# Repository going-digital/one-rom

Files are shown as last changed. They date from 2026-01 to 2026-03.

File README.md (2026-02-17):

# One ROM

**[One ROM](https://onerom.org) - One ROM To Rule Them All**

The most flexible ROM replacement for your retro computer.  It is highly configurable and low-cost.  Get them fabbed at JLC for under $5 each in a quantity of 10 or more.

Based on a Raspberry Pi RP2350 (One ROM Fire 🔥) or STM32F4 (One ROM Ice ❄️).

One ROM is available as 24 pin, 28 pin and 40 pin variants, emulating nearly all systems' 24 and 28 pin ROMs, plus 16-bit 40 pin ROMs used in systems like the Amiga A500.  One ROM supports any of the possible chip select configurations for 24 and 28 pin with a single hardware variant for that pin count, and can serve different images to multiple ROM sockets simultaneously.

Replaces failed ROMs in Commodore 64s, VIC-20s, PETs, Ataris, BBC, TIs, disk drives and many other types of systems, like pinball machines and music synthesizers.

ROM types replaced:
- 24 pin: 2704, 2708, 2716, 2732, 2316, 2332, 2364
- 28 pin: 2764, 27128, 27256, 27512, 23128, 23256, 23512, 231024
- 40 pin: 27C400

One ROM also supports RAM chips of the correct footprint, including the 6116 and 2016 2K SRAM chips.

One ROM shares firmware and configuration tools across all of its variants, making it a "one stop shop" for ROM replacement.

One ROM was formerly known as Software Defined Retro ROM (SDRR).

## Quick Start

See https://onerom.org/start/

## Hardware

These are the latest Fire 24 and 28 pin versions.  See [sdrr-pcb](sdrr-pcb/README.md) for all of the hardware designs and [current recommended revisions](sdrr-pcb/README.md#recommended-revisions).

<div style="display: flex; justify-content: center; gap: 20px;">
    One ROM RP2350 24 pin rev A side on
    One ROM RP2350 28 pin rev A side on
</div>

## Key Features

💰 Based on sub-$2 microcontrollers.  **[Choose from Raspberry Pi (Fire 🔥) or STM (Ice ❄️) flavours](docs/MCU-SELECTION.md)**.

⚡ **[Fast](docs/STM32-SELECTION.md)** enough for PETs, VIC-20s, C64s, BBCs, Ataris, TI-99, Apple II, 1541s, IEEE drives, etc. Support faster systems with higher end microcontroller.

📐 **[Same footprint](docs/images/sdrr-24-pin-side.png)** as original 24 and 28 pin ROMs - doesn't overhang the socket like other solutions.

🔌 **[USB Version](https://onerom.org/)** - no programmer required, program from your [browser](https://onerom.org/web) or [native desktop app](https://onerom.org/studio).

🚀 **[Quick programming](docs/PROGRAMMING.md)** - build and flash in <10 seconds.

🛠️ **[Reflash in situ](docs/PROGRAMMING.md)** - no need to remove the ROM from the host when reprogramming.

⚙️ **[Software configurable](docs/CONFIGURATION.md)** chip select lines - no hardware jumpers required.  Useful for replacing 23xxx series ROMs.

💾 Stores up to **[16 ROM images](docs/STM32-SELECTION.md)** of different sizes and chip select configurations.  Image selectable via jumpers.

📦 **[Replace multiple ROMs with one ROM](docs/MULTI-ROM-SETS.md)** a single One ROM 24 can replace up to 3 original ROMs e.g. all of C64 kernel, BASIC, character set.

🔀 **[Dynamic bank switching](docs/MULTI-ROM-SETS.md)** - switch between ROM images on the fly, e.g. different char ROMs with One ROM 24.

💻 **[Hackable at runtime](docs/RUNTIME-ACCESS.md)** - change the ROM images being served and access telemetry from the ROM at runtime using **[Airfrog](https://piers.rocks/u/airfrog)** or other SWD probes.

🧩 **[Images combined automatically](docs/CONFIGURATION.md)** - no need to manually build up your own larger PROM image containing multiple retro ROMs.

🏭 **[Two layer PCB](sdrr-pcb/README.md)**, component on single-side, limited BOM for low manufacturing cost/complexity.  Panelisable designs available for production quantities.

🔓 **[Open source](LICENSE.md)** software and hardware.

## Videos

Videos about One ROM, including demos, how-tos and technical deep-dives:

Video Title (https://www.youtube.com/playlist?list=PLXs34HaWLi12IR0gg25X8uovi9VFkOdlB)

## Documentation

The best place to started with One ROM is https://onerom.org/start/.

Links to other documentation provided below.

| Topic | Description |
|---|---|
| [Getting Started](docs/GETTING-STARTED.md) | Detailed instructions for flashing your One ROM |
| [Frequently Asked Questions](docs/FAQ.md) | Answers to common questions about One ROM. |
| [Building from source](ci/docker/README.md) | How to build the firmware from source using the provided Docker container. |
| [Installation](INSTALL.md) | Manual installation of build system dependencies. |
| [Programming](docs/PROGRAMMING.md) | How to program One ROM. |
| [Available Configurations](config/README.md#available-configurations) | Various pre-collated ROM collection configurations. |
| [MCU Selection](docs/MCU-SELECTION.md) | How to select the appropriate MCU for your application. |
| [Image Selection](docs/IMAGE-SELECTION.md) | How to tell One ROM which of the installed ROM images to serve. |
| [Image Sets](docs/MULTI-ROM-SETS.md) | How to use a single One ROM to support multiple ROMs simultaneously or to dynamically switch between images. |
| [Configuration](docs/CONFIGURATION.md) | One ROM configuration options. |
| [Runtime Access/Control](docs/RUNTIME-ACCESS.md) | Access and control the One ROM while it is serving ROMs. |
| [Compatibility](docs/COMPATIBILITY.md) | Compatibility with various retro systems. |
| [Logging](docs/LOGGING.md) | How to enable and use One ROM logging. |
| [Technical Summary](docs/TECHNICAL-SUMMARY.md) | Overview of the One ROM architecture, operation and design decisions. |
| [Technical Details](docs/TECHNICAL-DETAILS.md) | Technical details of the One ROM firmware and hardware. |
| [ROMs Glorious ROMs](docs/ROMS-GLORIOUS-ROMS.md) | Everything you ever wanted to know about 23/27 series ROMs but were afraid to ask. |
| [Custom Hardware](docs/CUSTOM-HARDWARE.md) | Guide on designing custom hardware for One ROM. |
| [Build System](docs/BUILD-SYSTEM.md) | How the One ROM build system works. |
| [Voltage Levels](docs/VOLTAGE-LEVELS.md) | How the One ROM supports the required logic voltage levels. |
| [Pi Pico Programmer](docs/PI-PICO-PROGRAMMER.md) | How to use a $5 Raspberry Pi Pico as a programmer for One ROM. |
| [Manufacturing Test](docs/MANUFACTURING-TEST.md) | Information on testing One ROM during manufacturing. |
| [STM32 Clones](docs/STM32-CLONES.md) | Information using STM32 clones with One ROM. |
| [Future Enhancements](docs/FUTURE-ENHANCEMENTS.md) | Possible future enhancements under consideration. |
| [License](LICENSE.md) | One ROM software and hardware licenses. |

## Debugging

The best place to start with debugging is [`Logging`](docs/LOGGING.md).  This will help you see what the One ROM is doing, and why it may not be working as expected.

If you have an [Airfrog](https://piers.rocks/u/airfrog), you can use it to inspect the One ROM firmware and its current state.

If you'd like a hand, raise an issue on the [GitHub issues page](https://github.com/piersfinlayson/software-defined-retro-rom/issues).  Please provide:

- the MCU you are using and the PCB type/revision
- the retro system you are trying to One ROM with
- any logging from One ROM
- ideally, the firmware image, if you are happy to share.

If you have built the firmware yourself, rather than using a pre-built release image, also provide:

- your build configuration
- the output from `make info-detail`.

## License

See [LICENSE](LICENSE.md) for software and hardware licensing information.

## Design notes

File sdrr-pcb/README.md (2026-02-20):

# sdrr-pcb

Contains SDRR PCB design files.  These are organised into two directories:

- [`verified/`](verified/README.md) - Verified designs that have been tested and work.
- [`unverified/`](unverified/README.md) - Unverified designs that have not been tested.

## Recommended Revisions

Last Updated 3rd February 2026.

I recommend Fire over Ice boards for most users.  See [MCU-SELECTION.md](../docs/MCU-SELECTION.md) for a comparison between Fire and Ice capabilities.

The following table lists the recommended verified designs.  Each design has been manufactured and assembled using JLCPCB's PCB assembly service, and verified to work correctly.

| Model | MCU | Pins | USB | SWD | Image Select Pins | X Pins | PCB |
|---|-----|---|-----|-----|---|---|---|
| Fire  | RP2350A | 24 | Micro-B | ✓ | 4 | 2 | [fire-24-d](./verified/fire-24-d/README.md) |
| Fire  | RP2354A | 24 | C | ✓ | 4 | 2 | [fire-24-e](./verified/fire-24-e/README.md) |
| Ice | STM32F4 | 24 | Micro-B | ✓ | 4 | 2 | [ice-24-j](./verified/ice-24-j/README.md) |
| Fire  | RP2350A or RP2354A | 28 | C | ✓ | 2 | n/a | [fire-28-a3](./verified/fire-28-a3/README.md) |
| Fire  | RP2350B or RP2354B | 40 | C | ✓ | 4 | n/a | [fire-40-a](./verified/fire-40-a/README.md) |

There may be later, unverified, revisions not in the list above.  These may have improvements over the recommended revisions, but they have not been verified to work.  If you want to use one of these later revisions, read the relevant README before ordering.

## Alternative Components

Sometimes your PCB manufacturer/assembler may be out of stock of a particular component.  This section lists some reasonable alternatives, using LCSC/JLC part numbers.

| Original Component | Original LCSC/JLC Part Number | Alternative Component | Alternative LCSC/JLC Part Number | Verified? | Notes |
|-|-|-|-|-|-|
| Diodes Inc AP2112K-3.3TRG1 | C51118 | Tech Public AP2112K-3.3TRG1 | C23380830 | No | Jelly bean part, same specs, should be fine |
| Raspberry Pi RP2350A | C42411118 | Raspberry Pi RP2354A | C41378174 | Yes | If using RP2354A, do not populate the external flash chip, as the RP2354A has internal flash. |
| Raspberry Pi RP2350B | C42415655 | Raspberry Pi RP2354B | C39843328 | Yes | If using RP2354B, do not populate the external flash chip, as the RP2354B has internal flash. |

The RP2354A can be replaced with the RP2350A _if the design supported external flash and it is populated_.
- Some designs, such as fire-24-e, do not support external flash, so the RP2354A cannot be replaced with the RP2350A.
- Some designs, such as fire-40-a, have hardware support for both external flash plus an RP2354B, so two lots of flash.  Fabricating this option requires the correct 0R resistors to be populated/not populated.  See the board schematic for more details.

In some cases, alternative BOM/POS files are already provided for some alternative components.  In other cases, you may need to edit the BOM/POS files yourself to substitute the alternative component.  _Always_ double check component values, part numbers and placement before ordering.

## Notes on Fabrication

All recommended designs have been manufactured and assembled using JLCPCB's PCB assembly service.  The gerbers and BOM/POS files in each revision's `fab/` directory are compatible with JLCPCB's requirements.

Some variants offer multiple sets of BOM/POS files or different combinations of components.  Read the relevant revision's README for details.

You need to exercise care when submitting the order to ensure the correct options are selected.  In particular:

- Select economic assembly, not standard assembly, for cost reasons.
- Use standard 1.6mm PCB thickness.  You probably want HASL with lead finish for cost reasons.
- You have to select the desired PCB colour as part of the PCB ordering process.  Red is recommended for Fire and blue for Ice.
- As of late 2025 you no longer need to remove JLC's order ID from the PCBs, but it is worth checking this is still the case when you place your order.
- After uploading the BOM and position files for assembly, you need to ensure all parts are available and checked.
- You must ensure JLC is showing the correct orientation for all components.  There are silkscreen markings for pin 1 on all ICs and polarized components - ensure this matches the pink dot of the component in the viewer.  Also ensure the USB connector is the correct orientation.

Occasionally, some chosen parts are out of stock on JLCPCB.  One ROM has been designed with extremely common parts where possible, which JLC tend to hold large stocks of.  However, if a part is unavailable you may need to select an alternative part.  Ensure the alternative part has the same footprint and electrical characteristics (e.g. capacitance, voltage rating, etc) as the original part.  If in doubt, query within github discussions for advice. 

JLC may raise an issue with you after submitting your order.  Common issues include:
- JLC may ask to add side rails with stamp holes, to help with the PCB assembly process.  While One ROM has been successfully fabbed without these, if JLC recommends them it is best to accept this change, as otherwise they may not warrant the assembled boards.  The side rails can be snapped off using the "mouse bites" (stamp holes) after assembly.  JLC may or may not accept replacing stamp holes with v-score - as v-score is not available on their economic service.

If in doubt, query within github discussions for advice.

Assembly errors:
- Ice boards have rarely, if ever, experienced assembly errors.
- The first few batches of Fire boards experienced some assembly issues, particularly with respect to the RP2350 MCU solder pad fillets.  More recent boards and orders have been without issue.  It is unclear whether differences in the later PCBs or improvements in JLC's assembly process are responsible for this improvement.  If you do experience assembly issues, raise with JLC support.  It would also be interesting to hear on github discussions what issues you experienced, so others can be aware.

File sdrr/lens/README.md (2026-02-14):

# One ROM Lens

This directory contains the source code for the One ROM Lens, a tool which runs the One ROM PIO algorithms in a browser and visualizes the results.

To build, first build the firmwre.  This must be done using the original `make` approach, as opposed to the newer `scripts/onerom.sh` approach.

```bash 
HW_REV=fire-24-e MCU=rp2350 ROM_CONFIGS=file=images/test/0_63_8192.rom,type=2364,cs1=0 make
```

Then, build and run One ROM Lens:

```bash
make -C sdrr -f lens.mk run
```

Point a browser at `http://localhost:8000` to access the One ROM Lens interface.

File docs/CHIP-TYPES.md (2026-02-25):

# Chip Type Specifications

This document provides detailed specifications for the different Chip types One ROM supports, and aims to support in future, including pinouts, control lines, and programming requirements.

The document is auto-generated from the [json/rom-types.json](/rust/config/json/rom-types.json) configuration file.  That file was created by researching datasheets for the various Chip types.

Some of the pin names have been modified from the datasheet values for consistency beween Chip types:

- /OE on 2704/2408 is called Program, but serves as /OE when in read mode.  Other 27xx ROMs use /OE for that pin, hence the /OE name is used here. 
- Similarly /CE on 2704/2708 ROMs is called /CS, but is called /CE for consistency with other ROM types.
- 23256/23512 chip select lines are often called CE/OE on datasheets, but are mask programmable to be active high or low, hence these are referred to within this doc as CS lines, like the other 23xx ROMs.

There are also some other inconsistencies between types:

- 2332's CS2 is pin 21 and pin 18 is A11.  On the 2316, CS2 is pin 18, and CS3 pin 21.
- The 2332's A11 is pin18, but the 2732's A11 is pin 21.

## Contents

- [24-pin Mask ROM Family (23xx)](#24-pin-mask-rom-family-23xx)
- [28-pin Mask ROM Family (23xxx)](#28-pin-mask-rom-family-23xx)
- [24-pin EPROM Family (27xx)](#24-pin-eprom-family-27xx)
- [28-pin EPROM Family (2764 and 27xxx)](#28-pin-eprom-family-27xx)
- [RAM Chips](#ram-chips)
- [Pin Function Comparison](#pin-function-comparison)
- [Detailed Pinouts](#detailed-pinouts)

## 24-pin Mask ROM Family (23xx)

| Chip Type | Size | Address Lines | Control Lines | Programming |
|---|---|---|---|---|
| 2316 | 2KB | 11 (A0-A10) | CS1 (pin 20), CS2 (pin 18), CS3 (pin 21) | None |
| 2332 | 4KB | 12 (A0-A11) | CS1 (pin 20), CS2 (pin 21) | None |
| 2364 | 8KB | 13 (A0-A12) | CS1 (pin 20) | None |

## 28-pin Mask ROM Family (23xx)

| Chip Type | Size | Address Lines | Control Lines | Programming |
|---|---|---|---|---|
| 23128 | 16KB | 14 (A0-A13) | CS1 (pin 20), CS2 (pin 22), CS3 (pin 27) | None |
| 23256 | 32KB | 15 (A0-A14) | CS1 (pin 20), CS2 (pin 22) | None |
| 23512 | 64KB | 16 (A0-A15) | CS1 (pin 20), CS2 (pin 22) | None |
| 231024 | 128KB | 17 (A0-A16) | CS1 (pin 20) | None |

## 24-pin EPROM Family (27xx)

| Chip Type | Size | Address Lines | Control Lines | Programming |
|---|---|---|---|---|
| 2704 | 512B | 9 (A0-A8) | /CE (pin 18), /OE (pin 20) | VPP: pin 18 (Low during read) |
| 2708 | 1KB | 10 (A0-A9) | /CE (pin 18), /OE (pin 20) | VPP: pin 18 (Low during read) |
| 2716 | 2KB | 11 (A0-A10) | /CE (pin 18), /OE (pin 20) | VPP: pin 21 (VCC during read) |
| 2732 | 4KB | 12 (A0-A11) | /CE (pin 18), /OE (pin 20) | VPP: pin 20 (Acts as /OE) |

## 28-pin EPROM Family (27xx)

| Chip Type | Size | Address Lines | Control Lines | Programming |
|---|---|---|---|---|
| 2764 | 8KB | 13 (A0-A12) | /CE (pin 20), /OE (pin 22) | VPP: pin 1 (VCC during read); /PGM: pin 27 (High during read) |
| 27128 | 16KB | 14 (A0-A13) | /CE (pin 20), /OE (pin 22) | VPP: pin 1 (VCC during read); /PGM: pin 27 (High during read) |
| 27256 | 32KB | 15 (A0-A14) | /CE (pin 20), /OE (pin 22) | VPP: pin 1 (VCC during read) |
| 27512 | 64KB | 16 (A0-A15) | /CE (pin 20), /OE (pin 22) | VPP: pin 22 (VCC during read) |
| 27C010 | 128KB | 17 (A0-A16) | /CE (pin 22), /OE (pin 24) | VPP: pin 1 (x); /PGM: pin 31 (x) |
| 27C301 | 128KB | 17 (A0-A16) | /CE (pin 22), /OE (pin 2) | VPP: pin 1 (x); /PGM: pin 31 (x) |
| 27C020 | 256KB | 18 (A0-A17) | /CE (pin 22), /OE (pin 24) | VPP: pin 1 (x); /PGM: pin 31 (x) |
| 27C040 | 512KB | 19 (A0-A18) | /CE (pin 22), /OE (pin 24) | VPP: pin 1 (x); /PGM: pin 22 (Acts as /OE) |
| 27C400 | 512KB | 19 (A0-A18) | /BYTE (pin 31), /CE (pin 10), /OE (pin 12) | VPP: pin 31 (word_size); /PGM: pin 10 (Acts as /OE) |
| 27C080 | 1024KB | 20 (A0-A19) | /CE (pin 22), /OE (pin 24) | VPP: pin 24 (Acts as /OE); /PGM: pin 22 (Acts as /OE) |

## RAM Chips

| Chip Type | Size | Address Lines | Control Lines | Programming |
|---|---|---|---|---|
| 6116 | 2KB | 11 (A0-A10) | /CE (pin 18), /OE (pin 20), /WRITE (pin 21) | None |

## Pin Function Comparison

### 24-pin Package

| Pin | 2316 | 2332 | 2364 | 2704 | 2708 | 2716 | 6116 | 2732 |
|-----|---|---|---|---|---|---|---|---|
| 1 | A7 | A7 | A7 | A7 | A7 | A7 | A7 | A7 |
| 2 | A6 | A6 | A6 | A6 | A6 | A6 | A6 | A6 |
| 3 | A5 | A5 | A5 | A5 | A5 | A5 | A5 | A5 |
| 4 | A4 | A4 | A4 | A4 | A4 | A4 | A4 | A4 |
| 5 | A3 | A3 | A3 | A3 | A3 | A3 | A3 | A3 |
| 6 | A2 | A2 | A2 | A2 | A2 | A2 | A2 | A2 |
| 7 | A1 | A1 | A1 | A1 | A1 | A1 | A1 | A1 |
| 8 | A0 | A0 | A0 | A0 | A0 | A0 | A0 | A0 |
| 9 | D0 | D0 | D0 | D0 | D0 | D0 | D0 | D0 |
| 10 | D1 | D1 | D1 | D1 | D1 | D1 | D1 | D1 |
| 11 | D2 | D2 | D2 | D2 | D2 | D2 | D2 | D2 |
| 12 | GND | GND | GND | GND | GND | GND | GND | GND |
| 13 | D3 | D3 | D3 | D3 | D3 | D3 | D3 | D3 |
| 14 | D4 | D4 | D4 | D4 | D4 | D4 | D4 | D4 |
| 15 | D5 | D5 | D5 | D5 | D5 | D5 | D5 | D5 |
| 16 | D6 | D6 | D6 | D6 | D6 | D6 | D6 | D6 |
| 17 | D7 | D7 | D7 | D7 | D7 | D7 | D7 | D7 |
| 18 | CS2 | A11 | A11 | /CE+VPP | /CE+VPP | /CE | /CE | /CE+PE |
| 19 | A10 | A10 | A10 | VDD | VDD | A10 | A10 | A10 |
| 20 | CS1 | CS1 | CS1 | /OE+PE | /OE+PE | /OE+PE | /OE | /OE+VPP |
| 21 | CS3 | CS2 | A12 | VBB | VBB | VPP | /WRITE | A11 |
| 22 | A9 | A9 | A9 | GND | A9 | A9 | A9 | A9 |
| 23 | A8 | A8 | A8 | A8 | A8 | A8 | A8 | A8 |
| 24 | VCC | VCC | VCC | VCC | VCC | VCC | VCC | VCC |

### 28-pin Package

| Pin | 23128 | 23256 | 23512 | 231024 | 2764 | 27128 | 27256 | 27512 |
|-----|---|---|---|---|---|---|---|---|
| 1 | NC | NC | A15 | A15 | VPP | VPP | VPP | A15 |
| 2 | A12 | A12 | A12 | A12 | A12 | A12 | A12 | A12 |
| 3 | A7 | A7 | A7 | A7 | A7 | A7 | A7 | A7 |
| 4 | A6 | A6 | A6 | A6 | A6 | A6 | A6 | A6 |
| 5 | A5 | A5 | A5 | A5 | A5 | A5 | A5 | A5 |
| 6 | A4 | A4 | A4 | A4 | A4 | A4 | A4 | A4 |
| 7 | A3 | A3 | A3 | A3 | A3 | A3 | A3 | A3 |
| 8 | A2 | A2 | A2 | A2 | A2 | A2 | A2 | A2 |
| 9 | A1 | A1 | A1 | A1 | A1 | A1 | A1 | A1 |
| 10 | A0 | A0 | A0 | A0 | A0 | A0 | A0 | A0 |
| 11 | D0 | D0 | D0 | D0 | D0 | D0 | D0 | D0 |
| 12 | D1 | D1 | D1 | D1 | D1 | D1 | D1 | D1 |
| 13 | D2 | D2 | D2 | D2 | D2 | D2 | D2 | D2 |
| 14 | GND | GND | GND | GND | GND | GND | GND | GND |
| 15 | D3 | D3 | D3 | D3 | D3 | D3 | D3 | D3 |
| 16 | D4 | D4 | D4 | D4 | D4 | D4 | D4 | D4 |
| 17 | D5 | D5 | D5 | D5 | D5 | D5 | D5 | D5 |
| 18 | D6 | D6 | D6 | D6 | D6 | D6 | D6 | D6 |
| 19 | D7 | D7 | D7 | D7 | D7 | D7 | D7 | D7 |
| 20 | CS1 | CS1 | CS1 | CS1 | /CE | /CE | /CE | /CE+PE |
| 21 | A10 | A10 | A10 | A10 | A10 | A10 | A10 | A10 |
| 22 | CS2 | CS2 | CS2 | A16 | /OE | /OE | /OE+PE | /OE+VPP |
| 23 | A11 | A11 | A11 | A11 | A11 | A11 | A11 | A11 |
| 24 | A9 | A9 | A9 | A9 | A9 | A9 | A9 | A9 |
| 25 | A8 | A8 | A8 | A8 | A8 | A8 | A8 | A8 |
| 26 | A13 | A13 | A13 | A13 | NC | A13 | A13 | A13 |
| 27 | CS3 | A14 | A14 | A14 | /PGM | /PGM | A14 | A14 |
| 28 | VCC | VCC | VCC | VCC | VCC | VCC | VCC | VCC |

## Detailed Pinouts

### 2316 - 2KB mask ROM with 3 configurable CS lines

**Package:** 24-pin DIP  
**Capacity:** 2048 bytes  
**Control:** 3 configurable CS lines  

| Function | Pins | Notes |
|---|---|---|
| Address (A0-A10) | 8,7,6,5,4,3,2,1,23,22,19 | 11 address lines |
| Data (D0-D7) | 9,10,11,13,14,15,16,17 | 8 data lines |
| CS1 | 20 | Configurable polarity |
| CS2 | 18 | Configurable polarity |
| CS3 | 21 | Configurable polarity |
| VCC | 24 | +5V |
| GND | 12 | 0V |

### 2332 - 4KB mask ROM with 2 configurable CS lines

**Package:** 24-pin DIP  
**Capacity:** 4096 bytes  
**Control:** 2 configurable CS lines  

| Function | Pins | Notes |
|---|---|---|
| Address (A0-A11) | 8,7,6,5,4,3,2,1,23,22,19,18 | 12 address lines |
| Data (D0-D7) | 9,10,11,13,14,15,16,17 | 8 data lines |
| CS1 | 20 | Configurable polarity |
| CS2 | 21 | Configurable polarity |
| VCC | 24 | +5V |
| GND | 12 | 0V |

### 2364 - 8KB mask ROM with 1 configurable CS line

**Package:** 24-pin DIP  
**Capacity:** 8192 bytes  
**Control:** 1 configurable CS line  

| Function | Pins | Notes |
|---|---|---|
| Address (A0-A12) | 8,7,6,5,4,3,2,1,23,22,19,18,21 | 13 address lines |
| Data (D0-D7) | 9,10,11,13,14,15,16,17 | 8 data lines |
| CS1 | 20 | Configurable polarity |
| VCC | 24 | +5V |
| GND | 12 | 0V |

### 23128 - 16KB mask ROM with 3 configurable CS lines

**Package:** 28-pin DIP  
**Capacity:** 16384 bytes  
**Control:** 3 configurable CS lines  

| Function | Pins | Notes |
|---|---|---|
| Address (A0-A13) | 10,9,8,7,6,5,4,3,25,24,21,23,2,26 | 14 address lines |
| Data (D0-D7) | 11,12,13,15,16,17,18,19 | 8 data lines |
| CS1 | 20 | Configurable polarity |
| CS2 | 22 | Configurable polarity |
| CS3 | 27 | Configurable polarity |
| VCC | 28 | +5V |
| GND | 14 | 0V |

### 23256 - 32KB mask ROM with 2 configurable CS lines

**Package:** 28-pin DIP  
**Capacity:** 32768 bytes  
**Control:** 2 configurable CS lines  

| Function | Pins | Notes |
|---|---|---|
| Address (A0-A14) | 10,9,8,7,6,5,4,3,25,24,21,23,2,26,27 | 15 address lines |
| Data (D0-D7) | 11,12,13,15,16,17,18,19 | 8 data lines |
| CS1 | 20 | Configurable polarity |
| CS2 | 22 | Configurable polarity |
| VCC | 28 | +5V |
| GND | 14 | 0V |

### 23512 - 64KB mask ROM with 2 configurable CS lines

**Package:** 28-pin DIP  
**Capacity:** 65536 bytes  
**Control:** 2 configurable CS lines  

| Function | Pins | Notes |
|---|---|---|
| Address (A0-A15) | 10,9,8,7,6,5,4,3,25,24,21,23,2,26,27,1 | 16 address lines |
| Data (D0-D7) | 11,12,13,15,16,17,18,19 | 8 data lines |
| CS1 | 20 | Configurable polarity |
| CS2 | 22 | Configurable polarity |
| VCC | 28 | +5V |
| GND | 14 | 0V |

### 231024 - 128KB mask ROM with 1 configurable CS line

**Package:** 28-pin DIP  
**Capacity:** 131072 bytes  
**Control:** 1 configurable CS line  

| Function | Pins | Notes |
|---|---|---|
| Address (A0-A16) | 10,9,8,7,6,5,4,3,25,24,21,23,2,26,27,1,22 | 17 address lines |
| Data (D0-D7) | 11,12,13,15,16,17,18,19 | 8 data lines |
| CS1 | 20 | Configurable polarity |
| VCC | 28 | +5V |
| GND | 14 | 0V |

### 2704 - 512B EPROM with multiple supply voltages

**Package:** 24-pin DIP  
**Capacity:** 512 bytes  
**Control:** /CE, /OE  

| Function | Pins | Notes |
|---|---|---|
| Address (A0-A8) | 8,7,6,5,4,3,2,1,23 | 9 address lines |
| Data (D0-D7) | 9,10,11,13,14,15,16,17 | 8 data lines |
| CE | 18 | Active low |
| OE | 20 | Active low |
| VPP | 18 | Low during read during read |
| PE | 20 | Low during read during read |
| VCC | 24 | +5V |
| VDD | 19 | +12V |
| VBB | 21 | -5V |
| GND | 12 | 0V |
| GND | 22 | 0V |

### 2708 - 1KB EPROM with multiple supply voltages

**Package:** 24-pin DIP  
**Capacity:** 1024 bytes  
**Control:** /CE, /OE  

| Function | Pins | Notes |
|---|---|---|
| Address (A0-A9) | 8,7,6,5,4,3,2,1,23,22 | 10 address lines |
| Data (D0-D7) | 9,10,11,13,14,15,16,17 | 8 data lines |
| CE | 18 | Active low |
| OE | 20 | Active low |
| VPP | 18 | Low during read during read |
| PE | 20 | Low during read during read |
| VCC | 24 | +5V |
| VDD | 19 | +12V |
| VBB | 21 | -5V |
| GND | 12 | 0V |

### 2716 - 2KB EPROM with fixed active-low CE/OE

**Package:** 24-pin DIP  
**Capacity:** 2048 bytes  
**Control:** /CE, /OE  

| Function | Pins | Notes |
|---|---|---|
| Address (A0-A10) | 8,7,6,5,4,3,2,1,23,22,19 | 11 address lines |
| Data (D0-D7) | 9,10,11,13,14,15,16,17 | 8 data lines |
| CE | 18 | Active low |
| OE | 20 | Active low |
| VPP | 21 | VCC during read during read |
| PE | 20 | Low during read during read |
| VCC | 24 | +5V |
| GND | 12 | 0V |

### 6116 - 2KB (2048 x 8-bit) Static RAM with fixed active-low CE/OE/WE

**Package:** 24-pin DIP  
**Capacity:** 2048 bytes  
**Control:** /CE, /OE, /WRITE  

| Function | Pins | Notes |
|---|---|---|
| Address (A0-A10) | 8,7,6,5,4,3,2,1,23,22,19 | 11 address lines |
| Data (D0-D7) | 9,10,11,13,14,15,16,17 | 8 data lines |
| CE | 18 | Active low |
| OE | 20 | Active low |
| WRITE | 21 | Active low |
| VCC | 24 | +5V |
| GND | 12 | 0V |

### 2732 - 4KB EPROM with fixed active-low CE and shared OE/VPP

**Package:** 24-pin DIP  
**Capacity:** 4096 bytes  
**Control:** /CE, /OE  

| Function | Pins | Notes |
|---|---|---|
| Address (A0-A11) | 8,7,6,5,4,3,2,1,23,22,19,21 | 12 address lines |
| Data (D0-D7) | 9,10,11,13,14,15,16,17 | 8 data lines |
| CE | 18 | Active low |
| OE | 20 | Active low |
| VPP | 20 | Acts as /OE during read |
| PE | 18 | Low during read during read |
| VCC | 24 | +5V |
| GND | 12 | 0V |

### 2764 - 8KB EPROM with fixed active-low CE/OE

**Package:** 28-pin DIP  
**Capacity:** 8192 bytes  
**Control:** /CE, /OE  

| Function | Pins | Notes |
|---|---|---|
| Address (A0-A12) | 10,9,8,7,6,5,4,3,25,24,21,23,2 | 13 address lines |
| Data (D0-D7) | 11,12,13,15,16,17,18,19 | 8 data lines |
| CE | 20 | Active low |
| OE | 22 | Active low |
| VPP | 1 | VCC during read during read |
| /PGM | 27 | High during read during read |
| VCC | 28 | +5V |
| GND | 14 | 0V |

### 27128 - 16KB EPROM with fixed active-low CE/OE

**Package:** 28-pin DIP  
**Capacity:** 16384 bytes  
**Control:** /CE, /OE  

| Function | Pins | Notes |
|---|---|---|
| Address (A0-A13) | 10,9,8,7,6,5,4,3,25,24,21,23,2,26 | 14 address lines |
| Data (D0-D7) | 11,12,13,15,16,17,18,19 | 8 data lines |
| CE | 20 | Active low |
| OE | 22 | Active low |
| VPP | 1 | VCC during read during read |
| /PGM | 27 | High during read during read |
| VCC | 28 | +5V |
| GND | 14 | 0V |

### 27256 - 32KB EPROM with fixed active-low CE/OE

**Package:** 28-pin DIP  
**Capacity:** 32768 bytes  
**Control:** /CE, /OE  

| Function | Pins | Notes |
|---|---|---|
| Address (A0-A14) | 10,9,8,7,6,5,4,3,25,24,21,23,2,26,27 | 15 address lines |
| Data (D0-D7) | 11,12,13,15,16,17,18,19 | 8 data lines |
| CE | 20 | Active low |
| OE | 22 | Active low |
| VPP | 1 | VCC during read during read |
| PE | 22 | Low during read during read |
| VCC | 28 | +5V |
| GND | 14 | 0V |

### 27512 - 64KB EPROM with fixed active-low CE/OE

**Package:** 28-pin DIP  
**Capacity:** 65536 bytes  
**Control:** /CE, /OE  

| Function | Pins | Notes |
|---|---|---|
| Address (A0-A15) | 10,9,8,7,6,5,4,3,25,24,21,23,2,26,27,1 | 16 address lines |
| Data (D0-D7) | 11,12,13,15,16,17,18,19 | 8 data lines |
| CE | 20 | Active low |
| OE | 22 | Active low |
| VPP | 22 | VCC during read during read |
| PE | 20 | Low during read during read |
| VCC | 28 | +5V |
| GND | 14 | 0V |

### 27C010 - 128KB EPROM with fixed active-low CE/OE

**Package:** 32-pin DIP  
**Capacity:** 131072 bytes  
**Control:** /CE, /OE  

| Function | Pins | Notes |
|---|---|---|
| Address (A0-A16) | 12,11,10,9,8,7,6,5,27,26,23,25,4,28,29,3,2 | 17 address lines |
| Data (D0-D7) | 13,14,15,17,18,19,20,21 | 8 data lines |
| CE | 22 | Active low |
| OE | 24 | Active low |
| VPP | 1 | x during read |
| /PGM | 31 | x during read |
| VCC | 32 | +5V |
| GND | 16 | 0V |

### 27C301 - 128KB EPROM with fixed active-low CE/OE

**Package:** 32-pin DIP  
**Capacity:** 131072 bytes  
**Control:** /CE, /OE  

| Function | Pins | Notes |
|---|---|---|
| Address (A0-A16) | 12,11,10,9,8,7,6,5,27,26,23,25,4,28,29,3,24 | 17 address lines |
| Data (D0-D7) | 13,14,15,17,18,19,20,21 | 8 data lines |
| CE | 22 | Active low |
| OE | 2 | Active low |
| VPP | 1 | x during read |
| /PGM | 31 | x during read |
| VCC | 32 | +5V |
| GND | 16 | 0V |

### 27C020 - 256KB EPROM with fixed active-low CE/OE

**Package:** 32-pin DIP  
**Capacity:** 262144 bytes  
**Control:** /CE, /OE  

| Function | Pins | Notes |
|---|---|---|
| Address (A0-A17) | 12,11,10,9,8,7,6,5,27,26,23,25,4,28,29,3,2,30 | 18 address lines |
| Data (D0-D7) | 13,14,15,17,18,19,20,21 | 8 data lines |
| CE | 22 | Active low |
| OE | 24 | Active low |
| VPP | 1 | x during read |
| /PGM | 31 | x during read |
| VCC | 32 | +5V |
| GND | 16 | 0V |

### 27C040 - 512KB EPROM with fixed active-low CE/OE

**Package:** 32-pin DIP  
**Capacity:** 524288 bytes  
**Control:** /CE, /OE  

| Function | Pins | Notes |
|---|---|---|
| Address (A0-A18) | 12,11,10,9,8,7,6,5,27,26,23,25,4,28,29,3,2,30,31 | 19 address lines |
| Data (D0-D7) | 13,14,15,17,18,19,20,21 | 8 data lines |
| CE | 22 | Active low |
| OE | 24 | Active low |
| VPP | 1 | x during read |
| /PGM | 22 | Acts as /OE during read |
| VCC | 32 | +5V |
| GND | 16 | 0V |

### 27C400 - 0.5MB EPROM with fixed active-low CE/OE

**Package:** 40-pin DIP  
**Capacity:** 524288 bytes  
**Control:** /BYTE, /CE, /OE  

| Function | Pins | Notes |
|---|---|---|
| Address (A0-A18) | 29,9,8,7,6,5,4,3,2,40,39,38,37,36,35,34,33,32,1 | 19 address lines |
| Data (D0-D7) | 13,15,17,19,22,24,26,28,14,16,18,20,23,25,27,29 | 8 data lines |
| BYTE | 31 | Active low |
| CE | 10 | Active low |
| OE | 12 | Active low |
| VPP | 31 | word_size during read |
| /PGM | 10 | Acts as /OE during read |
| VCC | 21 | +5V |
| GND | 11 | 0V |
| GND | 30 | 0V |

### 27C080 - 1MB EPROM with fixed active-low CE/OE

**Package:** 32-pin DIP  
**Capacity:** 1048576 bytes  
**Control:** /CE, /OE  

| Function | Pins | Notes |
|---|---|---|
| Address (A0-A19) | 12,11,10,9,8,7,6,5,27,26,23,25,4,28,29,3,2,30,31,1 | 20 address lines |
| Data (D0-D7) | 13,14,15,17,18,19,20,21 | 8 data lines |
| CE | 22 | Active low |
| OE | 24 | Active low |
| VPP | 24 | Acts as /OE during read |
| /PGM | 22 | Acts as /OE during read |
| VCC | 32 | +5V |
| GND | 16 | 0V |

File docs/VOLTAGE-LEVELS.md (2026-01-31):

# Voltage Levels

## Background

One of the biggest difficulties of this project, alongside hitting the timing requirements, was finding a microcontroller tha could support the 5V logic levels required by retro systems.

The STM32F1 series (64-bit variant) on the face of it has the required number of 5V tolerant (FT) GPIOs, but on further examination, there are not sufficient contiguous and starting at pin 0, FT pins on any port to hit the required performance - that is to allow the assembly code to perform optimal chip select comparisons, address lookups, and apply the results those to the data pins.

Therefore the STM32F4 series was initially chosen, followed by the RP2350, both to give sufficient raw horsepower (clock speed and flash instruction prefetch and cache), and also to provide the required FT hardware configuration.

There are two areas which are important to understand when considering voltage levels:
1. The logic level compatibility between One ROM and the retro system - that is, ensuring that One ROM's outputs are within the acceptable input levels of the retro system, and vice versa.  See [5V and 3.3V Logic Levels](#5v-and-33v-logic-levels).
2. The absolute maximum voltage levels that One ROM can tolerate on its pins, especially during power-on, when One ROM's MCU VDD is not yet at 3.3V.  See [Absolute Maximum VIN](#absolute-maximum-vin).

## 5V and 3.3V Logic Levels

As One ROM's purpose is to replace 5V logic level ROMs, it must be compatible with the voltage levels required by those systems.  We do this by examining and comparing the [STM32F411 datasheet](https://www.st.com/resource/en/datasheet/stm32f411re.pdf) (as a representative STM32F4 family chip) with the datasheets for the:

- [6502](http://www.6502.org/documents/datasheets/mos/mos_65ce02_mpu.pdf)
- [6567](http://www.6502.org/documents/datasheets/mos/mos_6567_vic_ii_preliminary.pdf) (C64 VIC-II chip)
- [6560/6561](http://www.6502.org/documents/datasheets/mos/mos_6560_6561_vic.pdf) (VIC-20 VIC chip)

(A similar analysis has been done for the RP2350, although at the highest GPIO drive strength, 12mA, the RP2350 strictly contravenes the requires specification.  Therefore One ROM Fire uses 8mA drive strength, which is within specification.)

### One ROM outputs, 6502 inputs

Note - One ROM's 5V outputs are the data lines, PA0-7.  These are set to "fast" speed, with IIO = +8mA.  We avoid "high" speed, as this can result in a maximum low output voltage VOL of 1.3V, which is too high for the 6502's maximum low input voltage VIL of 0.8V.

| One ROM VOL | 6502 VIL | 6567 VIL | 6560/6561 VIL |
|---|---|---|---|
| 0.4V | 0.8V | 0.8V | 0.4V |

One ROM's maxmimum low output voltage is less than the 6502/6567's maximum low input voltage, and the same as the 6560/6561, so we're good.

| One ROM VOH | 6502 VIH | 6567 VIH | 6560/6561 VIH |
|---|---|---|---|
| 2.4V* | 2.0V | 2.0V | 2.4V |

*Note it is highly likely the STM32F4 datasheet says that VOH is VDD-0.4V = 2.9V in this case - so we take 2.4V to be conservative.*

One ROM's maximum minimum output voltage is greater than the 6502/6567's minimum high input voltage, and the same as the 6560/6561, so we're good.

### One ROM inputs, 6502 outputs

| One ROM VIL | 6502 VOL | 6567 VOL | 6560/6561 VOL |
|---|---|---|---|
| 1.0V | 0.4V | 0.4V | 0.4V |

One ROM's minimum low input voltage is greater than the 6502/6567/6560/6561's maximum low output voltage so we're good.

| One ROM VIH | 6502 VOH | 6567 VOH | 6560/6561 VOH |
|---|---|---|---|
| 2.3V | 2.4V | 2.4V | 2.4V |

One ROM's minimum high input voltage is less than the 6502/6567/6560/6561's minimum high output voltage so we're good.

## Absolute Maximum VIN

According to the MCU datasheets, the absolute maximum rated voltage on any 5V tolerant pin is VDD + 4.0V for the STM32F4 and VDD + 3.63V on the RP2350.  There is also a 5.5V absolute maximum - so when VDD is at its usual 3.3V, the absolute maximum on any pin is 5.5V.

When VDD is 0V (before the voltage regulator is powering the chip), this means the absolute maximum voltage on any pin is 4.0V/3.63V (Ice/Fire).  When One ROM is installed in a retro system and powered on there is likely to be a 20us delay (see AP2112K-3.3TRG1 datasheet) between VCC being applied to One ROM and the voltage regulator outputting 3.3V to the MCU.

During this time then, technically, according to the MCUs' datasheets, the voltage on any GPIO must not exceed 4.0V/3.63V.  This is the case for most pins on most retro host systems as most systems have a reset circuit, and the bus master(s) are often held in reset for much longer than 20us - so most pins will be a 0V.  However, in some cases, some CS lines are permanently pulled to 5V, either through pull-ups or directly.  This means that 5.0V is applied to those pins for around 20us before VDD comes up to 3.3V.

System resets (where the internal host's reset line is used to reset the host system) typically do not trigger the 20us over-voltage scenario, as the MCU's VDD remains at already at 3.3V, as 5V remains applied to One ROM's VCC pin.  So, this applies to physical power-on (after power-off) events only.

To provide confidence in One ROM as a solution given its use strictly contravening the MCUs' datasheet figures, validation testing has been done with both Ice and Fire 24 boards, to ensure it is tolerant of 5.0V being applied to a single CS pin through a 0R resistor, across many power on events.

The test philosophy used was as follows:

- Use a 555 timer circuit to drive a transistor to power One ROM on and off - around 2.5s on, 1.5s off for a 4s/0.25Hz cycle.
- Hard pull (through a 0R resistor or wire) one CS pin (One ROM physical pin 20) to the 555/transistor switched VCC - i.e. it is powered at the same time as VCC is provided to One ROMs power pin, 24.
- Assume that a One ROM will receive, in heavy use, an average of 10 power cycles in any day = ~3600 cycles a year.  Hence one hour of testing (900 cycles) is equivalent to around 3 months of heavy use.
- Run the test for at least 24 hours = 6 years equivalent heavy use.
- After the test, validate that the all pins still operate correctly, by ensuring One ROM 24 can still serve a 2364 C64 kernal ROM in a C64.  If any address, data or CS line were damaged, the C64 would fail to boot.

Fire 24 serves as a reasonable proxy for Fire 28, as the designs are essentially identical, with a different GPIO mapping and couple more GPIOs used.

The 2.5s/1.5s timing was chosen, using convenient 555 circuit component values, to give One ROM plenty of time to fully boot and stabilise, and enough time for internal capacitors to meaningfully discharge during the off period, bringing VDD back down to close to zero before the next cycle.  Remember - during the period when VDD is 3.3V, all pins are fully 5v tolerant (up to 5.5V), so the testing is focused on the power-on period only.

Both Ice and Fire boards passed this test without issue.  The conclusion is that both One ROM Ice and Fire (using the STM32F4 and RP2350 respectively) can happily tolerate this over-voltage scenario under heavy use for extended periods of time.

The precise boards versions tested were:

- ice-24-f STM32F411RET6
- fire-24-d RP2350A, A4 stepping

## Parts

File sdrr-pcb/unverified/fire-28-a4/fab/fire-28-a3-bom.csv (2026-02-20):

Reference | Qty | Value | DNP | Exclude from BOM | Exclude from Board | Footprint | Datasheet | LCSC
C1,C2,C3,C7,C13,C15 | 6 | 4.7uF |  |  |  | Capacitor_SMD:C_0402_1005Metric | ~ | C23733
C4,C5,C6,C8,C9,C10,C11,C12,C14 | 9 | 0.1uF |  |  |  | Capacitor_SMD:C_0402_1005Metric | ~ | C1525
C16,C17 | 2 | 4.7uF |  |  |  | RP2350_60QFN_minimal:C_0402_1005Metric_small_pads | ~ | C23733
C18,C19 | 2 | 15pF |  |  |  | Capacitor_SMD:C_0402_1005Metric | ~ | C1548
D1 | 1 | LED_Small |  |  |  | LED_SMD:LED_0603_1608Metric | ~ | C2286
D2,D3 | 2 | 1N5819WS |  |  |  | Diode_SMD:D_SOD-323 |  | C191023
J1 | 1 | USB_C_Receptacle_USB2.0_16P |  |  |  | piers retro footprints:USB_C_connector_c2765186 | https://www.usb.org/sites/default/files/documents/usb_type-c.zip | C2765186
L1 | 1 | 3.3u |  |  |  | RP2350_60QFN_minimal:L_pol_2016 | ~ | C42411119
R1,R3,R7,R8 | 4 | 10K |  |  |  | Resistor_SMD:R_0402_1005Metric | ~ | C25744
R2,R5,R6 | 3 | 1K |  |  |  | Resistor_SMD:R_0402_1005Metric | ~ | C11702
R4 | 1 | 33R |  |  |  | Resistor_SMD:R_0402_1005Metric | ~ | C25105
R9,R10 | 2 | 5K1 |  |  |  | Resistor_SMD:R_0402_1005Metric | ~ | C25905
U1 | 1 | RP2350_60QFN |  |  |  | RP2350_60QFN_minimal:RP2350-QFN-60-1EP_7x7_P0.4mm_EP3.4x3.4mm_ThermalVias |  | C42411118
U3 | 1 | AP2112K-3.3 |  |  |  | Package_TO_SOT_SMD:SOT-23-5 |  | C51118
U4 | 1 | USBLC6-2P6 |  |  |  | Package_TO_SOT_SMD:SOT-666 | https://www.st.com/resource/en/datasheet/usblc6-2.pdf | C15999
U5 | 1 | W25Q16JVSS |  |  |  | Package_SON:Winbond_USON-8-1EP_3x2mm_P0.5mm_EP0.2x1.6mm | https://www.winbond.com/hq/support/documentation/levelOne.jsp?__locale=en&DocNo=DA00-W25Q16JV.1 | C2843335
Y1 | 1 | Crystal_GND24 |  |  |  | Crystal:Crystal_SMD_Abracon_ABM8G-4Pin_3.2x2.5mm | ~ | C20625731

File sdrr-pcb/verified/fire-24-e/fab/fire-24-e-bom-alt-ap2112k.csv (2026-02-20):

Reference | Qty | Value | DNP | Exclude from BOM | Exclude from Board | Footprint | Datasheet | LCSC
C1,C2,C7,C13,C15 | 5 | 4.7uF |  |  |  | Capacitor_SMD:C_0402_1005Metric | ~ | C23733
C3,C4,C5,C6,C8,C9,C10,C11,C12 | 9 | 0.1uF |  |  |  | Capacitor_SMD:C_0201_0603Metric | ~ | C668346
C16,C17 | 2 | 4.7uF |  |  |  | RP2350_60QFN_minimal:C_0402_1005Metric_small_pads | ~ | C23733
C18,C19 | 2 | 15pF |  |  |  | Capacitor_SMD:C_0201_0603Metric | ~ | C85891
D1 | 1 | LED_Small |  |  |  | LED_SMD:LED_0402_1005Metric | ~ | C25503345
D2,D3 | 2 | 1N5819WS |  |  |  | Diode_SMD:D_SOD-323 |  | C191023
J4 | 1 | USB_C_Receptacle_USB2.0_16P |  |  |  | piers retro:USB_C_connector_c2765186 | https://www.usb.org/sites/default/files/documents/usb_type-c.zip | C2765186
L1 | 1 | 3.3u |  |  |  | RP2350_60QFN_minimal:L_pol_2016 | ~ | C42411119
R1,R3,R7,R8 | 4 | 10K |  |  |  | Resistor_SMD:R_0201_0603Metric | ~ | C473048
R2,R5,R6 | 3 | 1K |  |  |  | Resistor_SMD:R_0201_0603Metric | ~ | C270365
R4 | 1 | 33R |  |  |  | Resistor_SMD:R_0402_1005Metric | ~ | C25105
R9,R10 | 2 | 5K1 |  |  |  | Resistor_SMD:R_0201_0603Metric | ~ | C270344
U1 | 1 | RP2350_60QFN |  |  |  | RP2350_60QFN_minimal:RP2350-QFN-60-1EP_7x7_P0.4mm_EP3.4x3.4mm_ThermalVias |  | C41378174
U3 | 1 | AP2112K-3.3 |  |  |  | Package_TO_SOT_SMD:SOT-23-5 |  | C23380830
U4 | 1 | USBLC6-2P6 |  |  |  | Package_TO_SOT_SMD:SOT-666 | https://www.st.com/resource/en/datasheet/usblc6-2.pdf | C15999
Y1 | 1 | Crystal_GND24 |  |  |  | Crystal:Crystal_SMD_Abracon_ABM8G-4Pin_3.2x2.5mm | ~ | C20625731

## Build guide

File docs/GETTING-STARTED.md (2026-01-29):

# Getting Started

## Contents

- [Important](#important)
- [USB One ROMs](#usb-one-roms)
- [Hardware Identification](#hardware-identification)
- [Programming One ROM via SWD (not USB)](#programming-one-rom-via-swd-not-usb)
- [Image Selection](#image-selection)
- [Bank Selection](#bank-selection)
- [Multi-ROM Sets](#multi-rom-sets)
- [Hardware Version Build Settings](#hardware-version-build-settings)
- [Recovering a Bricked Device](#recovering-a-bricked-device)

## Important

⚠️ **Do Not** externally power your One ROM device when it is installed in your retro system, other than via USB.

If the retro system is off or unplugged, this will cause your power supply and One ROM to attempt to power the entire 5V rail of your retro system, which may damage your One ROM, your retro system, your power supply or all of them.

You may program your One ROM when it is installed in your retro system, so long as it is powered on.  In this case **do not** provide external power.

⚠️ **Always** install One ROM in the correct orientation.  Pin 1 is clearly marked with a white L (corner) shape on the PCB.  The USB connector is always **at the other end** of the PCB from pin 1.

## USB One ROMs

Most people will be getting started with a USB One ROM device, which can be programmed over USB.  You are recommended to use either:

- [One ROM Studio](https://onerom.org/studio) - a desktop application for Windows, macOS and Linux
- [One ROM Web](https://onerom.org/web) - a web tool for programming One ROM from your browser.

See those links for more information on how to use those tools.

## Hardware Identification

Each variant of the One ROM hardware has a unique revision ID printed on the PCB, and the boards have different numbers of breakout pins at the top of the PCB.

Identify your One ROM hardware version using the following image - in particular look for the revision ID, or match with the number of pins at the top of the PCB.

Fire boards use the RP2350 microcontroller, Ice boards STM32.

Identify your One ROM Hardware Version

Not all later revisions are shown here - they are very similar to those shown, but with a different silkscreen marking.

## Programming One ROM via SWD (not USB)

You need an SWD programmer to program the One ROM hardware.  The Raspberry Pi Debug Probe and a Raspberry Pi Pico programmed as a Debug Probe are suitable programmers.  An ST-Link or any other SWD programmer should also work.

You need to connect 3 cables from the SWD programmer to the One ROM:
- SWDIO (data)
- SWCLK (clock)
- GND (ground)

For the programming pins locations see:
- [STM32 Revisions 24-D/E/F Programming Pins](#stm32-revisions-24-def-programming-pins)
- [STM32 Rev G and RP2350 Rev A Programming Pins](#stm32-rev-g-and-rp2350-rev-a-programming-pins)

You also need to power the One ROM in order to program it.  This is most easily done by installing it in a retro system, and powering it on.

Alternatively, you can power the One ROM from a 5V power supply by connecting to the 5V and GND [pins that usually connect the One ROM to the retro system](#external-power):
- GND to pin 12 (bottom left)
- 5V to pin 24 (top right)

At present, when using the standard One ROM programming utility `probe-rs`, the RP2350 version must also be manually put into DFU/bootloader mode to be programmed, by shorting BOOT to GND when One ROM is powered on.  See the [Recovering a Bricked Device](#recovering-a-bricked-device) section for details.

Once connected, you can run the appropriate `make` command from the repository root to build and flash the firmware.

### Example `make` Commands

One ROM rev G, STM32F405RG MCU, serving the standard set of C64 images:

```bash
HW_REV=24-g MCU=f405rg CONFIG=old-config/c64.mk run
```

One ROM rev A, RP2350 MCU, serving the standard set of VIC20 PAL images:

```bash
HW_REV=p24-a MCU=rp2350 CONFIG=old-config/vic20-pal.mk run
```

There are lots of other build configurations possible - see:
- [Hardware Version Build Settings](#hardware-version-build-settings) for standard `HW_REV` and `MCU` settings
- [config](/old-config/README.md) for a list of standard ROM image configurations
- [Advanced Configuration](/docs/CONFIGURATION.md) for other configuration options.

### Ice Revisions 24-D/E/F Programming Pins

Programming Pins for Revisions STM revs D/E/F

### Fire rev A and Ice Rev G Programming Pins

Programming Pins for Revisions STM rev G and RP rev A

### Fire rev C onwards and Ice Rev I Onwards Programming Pins

These are at the top of the board and are labelled on the underside of the board.

### External Power

External Power Pins

## Image Selection

One ROM supports a number of different ROM images being installed at once, with those images being selected by using the One ROM jumpers.  One ROM reads these jumpers at boot time to detect which image to serve.  Using this mechanism, One ROM will not dynamically switch between images while the retro system is running - see [Bank Selection](#bank-selection) below for dynamic switching.

The image select jumpers are always found at the top of the One ROM PCB, and differerent hardware revisions have different numbers of supported jumpers.

The images below show which jumper indicates which bit of the image selection value.  If closed, the bit is a 1, if open, the bit is a 0.  Therefore to select:
- image 0, leave all jumpers open
- image 1, close the jumper marked 0
- image 2, close the jumper marked 1
- image 3, close the jumpers marked 1 and 0
- etc.

If you select an image number higher than the total number of images installed, One ROM will start counting again from image 0.  For example:
- if you have 1 image installed, it will always be selected
- if you have 2 images installed, only bit 0 will take effect
- if you have 3 images installed and close jumper bits 1 and 0, image 0 will be selected (3 modulo 3 = 0)

### Fire Image Selection Jumpers

Fire 24 revision A has 3 image select jumpers, with the least significant bit on the **right**.  All subsequent Fire boards have the least significant bit on the right also, with the following number of image select jumpers:

Image Selection Jumpers for RP rev A

24 pin:

- A - 3
- B - 3
- C - 2
- D - 4

28 pin:

- A - 2

### Ice Revision 24-D Image Selection Jumpers

Revision D has 3 image select jumpers, with the least significant bit on the left.

Image Selection Jumpers for STM rev D

### Ice 24-E/F Image Selection Jumpers

Revisions E and F have 4 image select jumpers, with the least significant bit on the left.

Image Selection Jumpers for STM revs E/F

### Ice 24-G/H Image Selection Jumpers

Revision G has 5 image select jumpers, with the least significant bit on the **right**.

Image Selection Jumpers for STM revs G/H

## Ice 24-I/J Image Selection Jumpers

These revisions have 4 image select jumpers, with the least significant bit on the **right**.

## Bank Selection

When using [bank switched configurations](/docs/MULTI-ROM-SETS.md#dynamic-bank-switching-configuration) (those that start `bank-`), One ROM dynamically switches between images using the bank select jumpers ("X pins" or "expansion pins") X1 and X2.  These are always found at the top of the PCB.

Bank Selection Jumpers

Note that One ROM 28 does not have X pins. 

See the [Multi-ROM Sets](/docs/MULTI-ROM-SETS.md) documentation for more information on banks and multi-ROM sets.

## Multi-ROM Sets

When using [multi-ROM sets](/docs/MULTI-ROM-SETS.md#multi-rom-set-configuration) (those that start `set-`), One ROM serves ROM images up to 3 ROM sockets simultaneously, using pins X1 and X2 as extra chip select lines.  Connect flying leads from the X1 and X2 pins to the chip select pins of the other ROM sockets to be served.

Bank Selection Jumpers

Note that One ROM 28 does not have X pins. 

See the [Multi-ROM Sets](/docs/MULTI-ROM-SETS.md) documentation for more information on banks and multi-ROM sets.

## Hardware Version Build Settings

When building the One ROM firmware you must identify the hardware version and the MCU type to the build system.  The following table lists the identifiers to use for each hardware version:

| Type | Pins | PCB Revision ID  | `HW_REV=` | Supported `MCU=` | `STATUS_LED=` |
|---|---|-----|---|---|---|
| Fire | 24 | A | fire-24-a | rp2350 | 0/1 |
| Fire | 24 | B | fire-24-b | rp2350 | 0/1 |
| Fire | 24 | C | fire-24-c | rp2350 | 0/1 |
| Fire | 24 | D | fire-24-d | rp2350 | 0/1 |
| Fire | 28 | A/A2/A3 | fire-28-a | rp2350 | 0/1 |
| Ice | 24 | D | ice-24-d | f401rb/f401rc/f401re/f405rg/f411rc/f411re/f446rc/f446re | Not supported
| Ice | 24 | E | ice-24-e | f401rb/f401rc/f401re/f405rg/f411rc/f411re/f446rc/f446re | 0/1 |
| Ice | 24 | F/F2 | ice-24-f | f401rb/f401rc/f401re/f405rg/f411rc/f411re/f446rc/f446re | 0/1 |
| Ice | 24 | G | ice-24-g | f401rb/f401rc/f401re/f405rg/f411rc/f411re/f446rc/f446re | 0/1 |
| Ice | 24 | H | ice-24-h | f401rb/f401rc/f401re/f405rg/f411rc/f411re/f446rc/f446re | 0/1 |
| Ice | 24 | I | ice-24-i | f401rb/f401rc/f401re/f405rg/f411rc/f411re/f446rc/f446re | 0/1 |
| Ice | 24 | J | ice-24-j | f401rb/f401rc/f401re/f405rg/f411rc/f411re/f446rc/f446re | 0/1 |

Note that Fire boards can be fabbed with an RP2354 instead of the RP2350.  In this case the external flash should be un-populated.

## Recovering a Bricked Device

If your programmer will not connect to your One ROM device, or you have accidentally flashed incorrect firmware, you may have bricked your device and need to recover the device by forcing it into DFU/bootloader mode and then programming it using your SWD programmer as normal.

To enter DFU/bootloader mode, you must set the BOOT (Fire) or BOOT0 (Ice) pin to the correct level, and then reset the device, either by power cycling, replugging into USB or briefly pulling the RESET/RUN pin low.

## Fire

On the RP2350 BOOT must be pulled to GND, while resetting the device, to enter DFU/bootloader mode.  These should be shorted together to pull BOOT low.

Fire 24 rev A:

BOOT Pin Location - RP rev A

On Fire 24 B, BOOT and GND are exposed as pads on the board underside.

On Fire 24 C onwards and 28 A onwards, BOOT and GND are exposed at the top of the board and are labelled on the underside.

### Ice

On revisions D, E, and F, BOOT0 and 3.3V are exposed at the top right of the board as shown - short the two indicated pins together to pull BOOT0 high.

BOOT0 Pin Location - STM revs D/E/F

On revision G and H, BOOT0 and 3.3V are exposed at the bottom of the board as part of the programming pins, as shown.  Short the two indicated pins together to pull BOOT0 high.

BOOT0 Pin Location - STM rev G

On revisions I/J BOOT0 and 3.3V are exposed at the top of the board, and are labelled on the underside.

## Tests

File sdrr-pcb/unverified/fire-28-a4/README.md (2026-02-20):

# One ROM Fire 28 pin

**Unverified**

A4 revision of the 28 pin Fire ROM board.  Combined USB/Pro version with USB-C and SWD header pins.

This design only differs from A3 in a minor silkscreen clarification (see #121).

There are two versions of the BOM/POS files, which are unchanged from A3.

- The original version with an RP2350A and external flash
- A lower cost version with an RP2354A and no external flash

## Contents

- [Fab Files](fab/)
- [KiCad Design Files](kicad/)

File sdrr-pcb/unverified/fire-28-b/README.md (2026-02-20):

# One ROM Fire 28 pin

**Unverified**

Based on fire-28-a4, this design swaps out the horizontal USB-C connector for vertical one (i.e. that sticks up out of One ROM), to help when there is too little space at the bottom of a connector to plug in a cable.

This design is not preferred over fire-28-a - the two USB connector designs are complementary.

## Contents

- [Fab Files](fab/)
- [KiCad Design Files](kicad/)

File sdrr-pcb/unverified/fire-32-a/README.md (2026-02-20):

# One ROM Fire 32 pin

**Unverified**

Based on fire-40-a, this design is a prototype to add 32 pin One ROM support. 

## Contents

- [Fab Files](fab/)
- [KiCad Design Files](kicad/)

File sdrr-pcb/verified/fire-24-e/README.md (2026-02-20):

# Fire 24 Rev E

**Verified** - The standard version of this design has been verified.

`*-alt-ap2112k` provides an alternative AP2112K part, if the standard AP2112K-3.3 is not available.  This alternative part has not been verified.

23xx Fire (RP2350 24 pin) combined USB+SWD One ROM PCB.  Includes 4 image select jumpers.  Supports PIO and CPU serving algorithms.  USB-C.

This board is intended for production and panelisation:
- The move to USB-C makes panlisation simpler, with micro-B USB requiring cutouts in the PCB for each board in the panel.
- The board is now rectangular, making it easier to panelise.
- Pin assigment is slightly changed from D.
- Many passives moved to 0201 to make USB-C viable.  This is requires JLC standard assembly, but that is also required for panelisation.
- Requires RP2354A only (in-built flash), as no footprint for external flash is provided.  Again, this makes USB-C viable.

## Contents

- [Schematic](./fire-24-e-schematic.pdf)
- [Fab Files](fab/)
- [KiCad Design Files](kicad/)
- [Errata](#errata)
- [Notes](#notes)
- [Changelog](#changelog)
- [Panelisation](#panelisation)

## Errata

## Notes

In the 2332 base, CS1 and CS2 are non-contiguous.  This is a side-effect of making the 27xx OE/CE pins contiguous.  There is no way to make them both contiguous, and also make the X pins contiguous with the CS pin in the 2364 case.  This design makes the trade-off to keep the pins contiguous for more ROM types.  The PIO algorithm also supports non-contiguous CS pins, as used for the 2332, so this is not a problem.

## Changelog

Changes from USB rev E
- USB-C connector instead of micro-B.
- Rectangular board shape for easier panelisation.
- Some passives changed to 0201.
- Only supports RP2354A (in-built flash), as no footprint for external flash is provided.
- Pin assignment changes.

## Panelisation

This revision is intended for panelisation.
- With JLC, when selecting the number of PCBs, choose the number panels.
- Under panlisation, choose "by JLC" and choose the number of boards per panel (e.g. 5 columns x 4 rows = 20 boards per panel), plus edge rails (left and right).
- JLC will automatically add V-grooves.
- Under assembly, when selecting BOM/POS file, select "single piece help me repeat", and JLC will include X times the components for X boards in the panel x the number of panels (PCBs).

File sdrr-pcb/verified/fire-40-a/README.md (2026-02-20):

# One ROM Fire 40 pin 

**Verified** - The "rp2354-and-flash" design has been verified serving a 27C400 16-bit 40-pin ROM on an Amiga A500.

The "rp2354-no-ext-flash" has not yet been verified.

The functionality of the external flash has not been verified.  This design has only been tested using the RP2354B with built in flash.  While external flash is also present on the tested boards, it has not been verified, or that the design works with an RP2350.

Odds are good that all will work, but buyer beware.

## Contents

- [Schematic](./fire-40-a-schematic.pdf)
- [Fab Files](fab/)
- [KiCad Design Files](kicad/)
- [Errata](#errata)
- [Notes](#notes)
- [Changelog](#changelog)
- [BOM](#bom)

## Errata

## Notes

The fab files assume this is fabbed with both an RP2354B (i.e. containing 2MB flash on-board) _and_ external 2MB flash, with the appropriate R11/R12 configurations.  To have other variants assembled:
- RP2354 without external flash, do not populate U5 or R12
- RP2350 with external flash, do not populate R12, instead populate R11 with 0R resistor, U5 populated.

The RP2354B variant is recommended, if RP2354B parts are available, as it is cheaper than RP2350B + external flash.  External flash is also useful, to increase the number of ROM images that can be stored and selected at boot time, from 3 (internal flash only) to 7 (with external flash).

This board requires both top and bottom assembly, as many passives are located on the bottom side.  This requires JLC's standard PCB assembly (with higher costs as a result).  If the boards are fabbed individually (not panelised), JLB will require additional side rails to be added to bring the board up to their minimum PCB size for assembly (roughly 70mm x 70mm).  JLC will recommend this automatically during the ordering process.

As ever, take care that every parts is positioned correctly before ordering.  In particular note the pink pin one dot is located in the appropriate corner for each IC, and that diodes are oriented correctly.

JLC queried the first run of these boards, specifically whether D1 (the status LED) was oriented correctly, as due to aesthetic reasons, a negative marker is not present on the silkscreen.  Negative should be to the left, when viewing the board top with the silkscreen upright.

## Changelog

## BOM

See fab files.

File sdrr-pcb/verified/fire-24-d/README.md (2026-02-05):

# Fire 24 Rev D

**Verified** - both RP2350 and RP2354 versions.

23xx Fire (RP2350 24 pin) combined USB+SWD One ROM PCB.  Includes 4 image select jumpers.  Supports PIO and CPU serving algorithms.

Note that firmware version v0.6.1+ is required to support 4 image select jumpers - v0.6.0 only supports the first 2.

There are two variants of the BOM/POS files - one with the RP2350A and external flash, the second with the RP2354, which has built-in flash, so the external flash is omitted.  The RP2354 version is cheaper.

## Contents

- [Schematic](./fire-24-d-schematic.pdf)
- [Fab Files](fab/)
- [KiCad Design Files](kicad/)
- [Errata](#errata)
- [Notes](#notes)
- [Changelog](#changelog)

## Errata

## Notes

In the 2332 base, CS1 and CS2 are non-contiguous.  This is a side-effect of making the 27xx OE/CE pins contiguous.  There is no way to make them both contiguous, and also make the X pins contiguous with the CS pin in the 2364 case.  This design makes the trade-off to keep the pins contiguous for more ROM types.  The PIO algorithm also supports non-contiguous CS pins, as used for the 2332, so this is not a problem.

## Changelog

Changes from USB rev D
- Connected additional sel GPIOs to SWDIO/SWCLK pins for up to 4 image select pins.

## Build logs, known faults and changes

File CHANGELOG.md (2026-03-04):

# Changelog

All notables changes between versions are documented in this file.

## v0.6.7 - ????-??-??

Introduced fire-24-eadb01 as a possibly temporary workaround for a single fire-24-e board.  Do not rely on this hardware version, as it may be removed without warning in future.

## v0.6.6 - 2026-02-25

The headline for this release is "bug fixes and other improvements".

There are also a significant number of fixes and improvements to the remainder of the One ROM fold, including some changes to existing behaviour, listed first:

- Improved regular (not 16 bit forced) /BYTE serving algorithm for 40 pin ROM, #153.

  This algorithm is marginally slower than previously but more robust.  If a faster algorithm is required, sacrifice /BYTE low handling with firmware_overrides->fire->force_16_bit = true in the ROM config.

- Resolved deficiencies in fire-24-a and fire-24-b PIO serving modes, #94.  All function is now supported on these boards, except for dynamic bank switching, which will likely remain unimplemented on these boards due to the lack of contiguity between X1/X2 and the CS pins.

  As a result fire-24-a and fire-24-b now default to PIO serving.  If CPU is desired (for example, for dynamic bank switching support), use firmware_overrides in the JSON config file.

- Changed default HW_REV/MCU in Makefile to fire-24-e/rp2350 (from ice-24-f/f401rc).  This only impacts using the old style `make` builds, not `scripts/onerom.sh` builds.

- All supported ROM types and CS configurations are now fully PIO tested as part of automated (CI) regression testing, for all Fire hardware revisions, #149.

- Fixed support for 2 ROM multi-ROM sets, for Fire boards in PIO mode, #110.  This impacted all Fire revisions in PIO mode - in particular the provided 1541 multi-ROM config did not work (and now does). 

- Forced unused address lines to appear driven low to the MCU for appropriate ROM types, to fix #154.

  This probably doesn't have any external impact, but if so it would be to 27 series ROMs and/or 2 set multi-ROM sets (24 pin only).  All supported 27 series ROM types have been tested manually with this change, as has 2 ROM multi-ROM sets on 24 pin boards.

- Implemented 2704 and 2708 ROM support on all existing Ice and Fire 24 pin boards, #156.

  2704/2708 support was tested on a T48 EPROM reader (with Pin Detect disabled), as a 2716 (as the T48 software doesn't support 2704/2708).  The 2704 image was correctly duplicaetd 4 times in the 2716 space and the 2708 twice.  Support for 2704/2708/2716 and 2732 was tested on fire-24-a and fire-24-e, both with PIO serving, and ice-24-j.

- This releases adds _prototype_ support for One ROM 32 #131 including:
  - Hardware revision fire-32-a
  - EPROM types 27C010, 27C020, 27C040 and 27C301
  - Support for 27C080 is included allowing two physically stacked One ROMs to be configured, each to serve half of the 27C080.  The one serving the lower 512KB should have cs1 set active low and the other one should have cs1 active high in their respective ROM configs.
  This support has been tested using the PIO emulator, but has not been tested with real hardware.  It is expected that bug fixes will be required when testing is done with real hardware, and One ROM 32 will be formally supported in a later release.

## v0.6.5 - 2026-02-22

The big new feature in this release is support for One ROM 40, hardware revision fire-40-a.  This emulates a 27C400 found in the Amiga A500, and other 16-bit systems.  I have successfully tested it on my Amiga, serving Kickstart ROM 1.3 and [DiagROMV2](https://www.diagrom.com/).

One ROM Lens is also included.  This is a web-based tool that runs the real One ROM serving algorithm within your web browser using a cycle exact PIO emulator.  It emulates One ROM's operation, allowing you to inspecting the GPIOs on a cycle by cycle basis using the logic analyzer style interface.  This is a great tool for understanding how One ROM (or any parallel ROM) works, for debugging firmware issues and interatively testing algorithm changes. To use, there are two steps:

1. Build the One ROM firmware, using an "old-style" config, with the emulated hardware type and image you want One ROM to serve: e.g. `HW_REV=fire-40-a MCU=rp2350 CONFIG=old-config/test/40-random.mk make`.
2. Build and run One ROM Lens: `make -C sdrr -f lens.mk serve`.

    Then point a browser at http://localhost:8000/index.html.

    It is likely that simpler commands will be added to the future to make this easier.

This release also introduces extensive automated regression testing for the Fire PIO serving algorithm (#134), for 24 and 28 pin boards.  As a result, a number of Fire PIO serving bugs have been fixed, including #110 and #94.

## v0.6.4 - 2026-02-07

- Fixed [#133](https://github.com/piersfinlayson/one-rom/issues/133), a complex issue where Studio v0.10 and earlier fail to build 28 pin v0.6.3 firmware images correctly.  This stemmed from 0.6.3 incorrectly including a non-backwards compatible change in order to support 231024 ROM types. As part of this:
  - v0.6.4 reverts that non-backwards compatible change, but retains 231024 support.  Specifically non-231204 ROM images use 64KB on flash, with only 231024 requiring 256KB.
  - v0.6.4 also introduces checking that the ROM image type is as expected and enters limp mode if not - rather than pretending to be OK and serving garbage.
  - Studio has been enhanced so it can be configured at runtime (via the manifest) with a maximum firmware version it can support - which overrides onerom-gen's maximum version, if the version Studio is allowed to build is lower.  Had this been in place earlier it could have been used to prevent pre-v0.1.11 version of Studio building bugged v0.6.3 firmwares, when #133 was found.

## v0.6.3 - 2026-02-03

- Added 231024 mask programmed ROM support.  Used by BBC Master and Apple IIgs.  (Only tested on BBC Master.)
- Add some Studio keyboard shortcuts (r for rescan, f for flash).

## v0.6.2 - 2026-01-27

This release of One ROM introduces RAM support - for 6116 and 2016 2KB 24-pin static RAM chips, using Fire 24 C and onwards hardware revisions.

For a demonstation of RAM support, and an explanation of how it works, see: https://youtu.be/o7dMY6p6OJU

One ROM's JSON [config file format](onerom-config/README.md) now uses "chip_sets" instead of "rom_sets" and "chips" instead of "roms".  However, the old strings will continue to work for backwards compatibility.

Other changes:
- The ability to execute the main loop from RAM has been removed, to allow 512KB to be used for ROM RAM image on RP2350.  It would be possible to add this back where the image size to be held in RAM is under 512KB, and for Ice boards, but as executing from RAM is currently unused, it has been removed for now to save development and test effort.
- fire-24-e revision added as **unverified**.  This adds USB-C, and is intended for production quantities of Fire 24 - as it required JLC's standard assembly service to be used, rather than economic, due to the use of 0201 passives.  The MCU has also been changed to the RP235A, to take advantage of the on-board flash, saving on cost (and space).
- Rename directories `config/` -> `old-config` and `rom-config` -> `onerom-config`.
- The new recommended by to build One ROM firmware is using [`scripts/onerom.sh`](scripts/onerom.sh).  This builds an empty firmware image, adds the chip metadata, and adds the ROM/RAM images in one command.  It even flashes the firmware if desired.  Images are output to [`builds/fw`](builds/fw).

## v0.6.1 - 2026-01-22

### Added

- Prototype RAM support for 24 pin RAM chips, which use the same pin-out as the 6116/2016 RAM.  See PR #98 and discussion #70. Requires building from command line using make and EXTRA_C_FLAGS=-DONE_RAM
- Support for Fire boards (fire-24-d specifically) to use image select pins that are shared with SWD pins.  Note that this means that having an SWD programmer connected at boot will tend to change the image select value to an unexpected one, as the pins will be pulled by the programmer.  In v0.6.0 only 2 image select jumpers were supported on fire-24-d.
- Support for Ice boards (ice-24-j specifically) to use image select pins that are shared with SWD pins.  Note that this means that having an SWD programmer connected at boot may change the image select value to an unexpected one, as the pins will be pulled by the programmer.  In v0.6.0 only 2 image select jumpers were supported on ice-24-j.  Also, unlike the Fire boards, the ice-24-j (and similar) boards will disconnect from the debug probe during boot because of this function, so reconnecting will be necessary.
- Check in Studio/onerom-gen that firmware version is not too new (next major release) when building firmware images.
- Promote fire-24-d and ice-24-j to verified hardware revisions.

### Fixed

- Fixed #90 in v0.6.0 when older (pre v0.1.8) versions of One ROM Studio are used to build firmware images with more than one ROM set, One ROM will not boot on any ROM set other than ROM set 0.
- 2732 ROM type serving was broken - the top 2K replicated the bottom 2K.  Fixed (#103).  This included fixing the testing, which had also not caught this issue.

### Fixed

- 2732 ROM type serving was broken - the top 2K replicated the bottom 2K.  Fixed (#103).  This included fixing the testing, which had also not caught this issue.

## v0.6.0 - 2026-01-14

**EXPERIMENTAL RELEASE** - may contain bugs, use with caution.  If you hit problems, report them as issues and revert to v0.5.10 or earlier.  See [#87](https://github.com/piersfinlayson/one-rom/pull/87) for details of testing done.

This major release of the One ROM firmware adds support for low-level One ROM firmware configuration from the ROM config files, allowing per-ROM image configuration of processor clock speed, status LED behaviour, and other low-level capabilities from One ROM Studio, and other tools.

As a major firmware release, there are some non-backwards compatible changes in this release:

- The ROM config JSON schema has changed - `sel_jumper_pull` is now a Vec<u8>, to allow per-pin SEL jumper pull direction.
- The default PIO configuration is now SLOW_CHAR_CHAR, to improve ROM serving compatibility.  PIO configuration can be overriden on a per ROM set basis using `serve_alg_params` firmware overrides.

### Added

- Support for per-ROM image low-level configuration, including processor clock speed, status LED behaviour, and other low-level capabilities.  See the ROM Config [README](rom-config/README.md) for details.
- Support for fire-24-d and ice-24-j hardware revisions.
- Enhanced onerom-fw CLI tool to receive a local firmware file.
- One ROM Studio v0.1.8.
- Firmware v0.6.0.

### Changed

- ROM config JSON schema change - `sel_jumper_pull` is now a Vec<u8>, to allow per-pin SEL jumper pull direction.
- PIO support is now built into all RP2350 firmwares, and is enabled/disabled by default using RP_PIO build flag.
- RP2350 no longer enters filesystem mode when USB connected - only PICOBOOT protocol supported.

### Known Limitations

- The firmware does not support image select pins shared with SWD pins.  At present image select pins shared with SWD pins are ignored.
  - This is expected to be added in a future release.
  - It is relevant for `fire-24-d` and `ice-24-j` hardware revisions.
  In additon, the configurable per-pin jumper sel behaviour has not been explicitly tested.
- `swd_enabled`: false is not yet functional.  (It is not clear that this is a good idea anyway, as it would make a non-USB board more difficult to reprogram.)  This setting may be removed in a future release.

## v0.5.10 - 2026-01-03

Promote fire-24-c to verified and recommended 24-pin Fire version.

### Added

- issue #77 - Support for serving multi-ROM sets using Fire PIO algorithm.
- ROM types for 32 and 40 pin ROMs

### Changed

- issue #78 - Move RAM ROM image to 0x2000_0000 to prepare for 40 pin versions.

### Fixes

- issue #76 - fire-24-c PIO algorithm fixes.

## v0.5.9 - 2026-01-01

This release adds new One ROM hardware revisions and ROM type support.

### Added

- 231024 (28 pin) ROM type support.
- Hardware revision ice-24-i - Combined Pro (SWD) and USB 24 pin Ice version.
- Hardware revision fire-24-c - Combined Pro (SWD) and USB 24 pin Fire version.
- Hardware revisions fire-28-a2 and fire-28-a3 - Combined Pro (SWD) and USB 28 pin Fire versions.

### Crates

- onerom-config 0.2.5, 0.2.6
- onerom-fw 0.1.5, 0.1.6
- onerom-gen 0.2.3, 0.2.4
- sdrr-fw-parser 0.5.7, 0.5.8

## v0.5.8 - 2025-12-12

This release adds 28 pin ROM support for the new One ROM Fire 28-pin version, fire-28-a.

### Added

- Support for 28 pin ROM types using fire-28-a.  23128 has been tested in a C64C. wotj 2764, 27128, 27256 and 27512 tested in an EEPROM reader.  It is STRONGLY recommended NOT to use an EEPROM reader to read One ROM, as it may apply 12V to pin A9.

## v0.5.7 - 2025-12-09

### Fixed

- Erroneous CE/OE pin numbers for 2716/2732 ROMs.

## v0.5.6 - 2025-12-09

### Added

- Support for 2716/2732 ROMs (2716 tested).
- PIO support for 2316/2716/2732 ROMs (untested)
- Studio 0.1.4

### Fixed

- Comment in Makefile - B is now default serving algorithm.

## v0.5.5 - 2025-11-18

This release adds support for the RP2350 One ROM serving ROMs using the RP2350's PIO/DIO peripheral, allowing fully autonomous ROM serving without any CPU involvement.  A VIC-20 kernal can be served successfully with the RP2350 clocked at just 22MHz, the C64 kernal at 41MHz and the both systems' character ROMs at 51MHz.  There are some limitations, meaning this is not yet the default Fire algorithm:
- Dynamically bank switched ROMs _are_ supported.
- Only CS lines which are contiguous are supported - hence the 2316 is _not_ supported on either rev A or USB rev B.
- Multi-ROM sets, via X1/X2, are _not_ supported, as they are not contiguous with the CS lines in current hardware.

For full support a hardware revision must order the CS lines contiguously either:
- X2/X1/CS1/A12/A11 or
- A11/A12/CS1/X1/X2

To build use `EXTRA_C_FLAGS=-DRP_PIO` when running `make`.  See `sdrr/src/piorom.c` for further details of the PIO/DMA algorithm, and configuration options.

### Fixed

- Enabled FP extensions on both Ice and Fire to avoid hard fault if floating point instructions are used by the compiler.

## v0.5.4 - 2025-11-12

This release adds support for the One ROM Fire (RP2350) USB version, via hardware revision `fire-24-usb-b`.  Current USB support is per Ice - plugging in USB disables ROM serving, and puts the RP2350 into DFU mode to allow firmware updates.  A future release is expected to add Fire USB support in parallel to ROM serving. 

### Added

- Added first RP2350 USB version, [Fire 24 USB B](sdrr-pcb/unverified/fire-24-24-b/README.md), as unverified.
- Added [Ice 24 USB H3](sdrr-pcb/unverified/one-rom-ice-usb-h3-24-pin/README.md) as unverified.
- Moved [Ice 24 USB H2](sdrr-pcb/verified/one-rom-ice-usb-h2-24-pin/README.md) to verified.

### Added

- `onerom-config` 0.2.2 - Added method to query ROM power pins.
- Studio:
    - See [rust/studio/CHANGELOG.md](rust/studio/CHANGELOG.md) for details.
    - Studio is released independently of firmware - see `studio-*` github tags.
- ROM Configs:
    - Blank ROM config (for manufacturing/testing) - /rom-configs/blank.json
    - Added pincoder 2021 version system 3, 5, 6 and 7 ROM configs (2332 ROMs)
- Allow `sdrr-fw-parser` to parse up to v0.5.999 firmware versions. 

### Fixes

- [#43](https://github.com/piersfinlayson/one-rom/issues/43) - Let sdrr-fw-parser parse later versions of fw. Supports up to v0.5.999 with no code/wasm/site changes required.
- Allow multi-ROM sets to be built in One ROM Studio.  Unsure when this was regressed

## v0.5.3 - 2025-10-24

The major addition in this release is the companion desktop application, One ROM Studio, which provides a native GUI for creating One ROM firmware images, and analysing and flashing One ROM devices.

One ROM Studio on Windows

Features include:
- Supported platforms: Windows, Mac, Linux (Ubuntu, Debian and Raspberry Pi OS)
- Supported One ROMs: all variants including Ice/Fire and Pro/USB
- Program One ROMs with a choice of ROM images
- Generate and save One ROM firmware files
- Analyse One ROM devices and firmware files
- Automatic debug probe and One ROM USB detection

One ROM Studio can be downloaded from https://onerom.org/studio/.

### Added

- Added "limp mode" support to detect when an incompatible firmware has been flashed to an Ice One ROM.  It blinks fast in this state and, if it is a USB model, allows the device to drop into DFU mode when USB is connected, to allow flashing of a compatible firmware.  Note that "slower" MCU firmwares are permitted by "faster" MCUs - but not the other way around.  See #37 for details.

### Fixes

## v0.5.2 - 2025-10-14

New in this release is a command line firmware image creation tool `rust/fw`.  This dynamically creates a custom One ROM firmware image from a specified:
- set of ROM images (specified as a JSON config file)
- model, board and MCU type (specified as command line arguments)
- optional firmware version (defaults to the latest version available)

To build:
```bash
cd rust/fw
cargo build --release --bin onerom-fw
# Binary is located at /rust/target/release/onerom-fw
```

This is a precursor to simplifying the CI builds to avoid having to create every combination of hardware/ROM config as build artifacts.  The hardware combinations can be pre-built with empty metadata and ROM image data, and this tool then composes a complete firmware image, ready for flashing.

As v0.5.1, and empty firmware image can also be flashed - One ROM then blinks its status LED slowly, and can have metadata and ROM images flashed to it later.

The complete list of available "empty" hardware configuration firmwares can be found at https://images.onerom.org/releases.json.

This command line tool may also be augmented with a native GUI, in parallel to the web-based tool at https://onerom.org/prog/.

### Changes

- Improved `onerom-gen` testing, and improved `onerom-config` and `onerom-gen` validation.

### Fixes

- Fix rust/gen/tests for boards with address lines all >=8.
- Fix `sdrr-info` processing of firmware from v0.5.1 onwards with detailed metadata content in a valid, but unexpected, order.

## v0.5.1 - 2025-10-13

For the average user, there are no particularly notable changes in this release, except the addition of the [Atari 800XL BASIC ROM config](/config/atari800xl.mk).

The firmware generator process underwent a major overhaul in this release:
- Support ROM types and hardware (PCB) revisions are now parsed at build time, which can be included in Web Assembly code.
- `sdrr-common` has been retired and mostly replaced with `onerom-config`
- Much of `sdrr-gen` has been moved out to `onerom-gen` crate, which can be used in other Rust projects, including Web Assembly.
- There is a new `onerom-wasm` crate at https://github.com/piersfinlayson/one-rom-wasm, which can be used to build Web Assembly code to generate One ROM firmware images in the browser.  Web Assembly packages, documentation and examples are located at https://wasm.onerom.org/.
- A metadata and ROM-less firmware can be built with `EXCLUDE_METADATA=1`.  When flashed with ths firmware, One ROM blinks its status LED slowly.  It can subsequently have metadata and ROM image fragments flashed, and, when reset, serves the newly flashed images.  This is expected to be useful for release artifacts and manufacturing, as a single firmware per hardware variant per release can be built, with metadata and ROM images added later, rather than the current need to build a firmware per hardware variant **per configuration** per release.

There is more work planned to the firmware upgrade process, including multi-stage USB device updates using the new capabilities, but this release has laid the groundwork and enabled some exciting new web-based features.

Also, the first, prototype 28 pin ROM support using hardware revision `ice-28-a` is in this release.  It successfully emulates a 27128 ROM (i.e. without the 3rd CS line on a 23128).  It has been tested successfully on a C64C, replacing the combined KERNAL/BASIC ROM with a One ROM Ice 28 A, clocked at just 55MHz using an STM32F446RCT6. This hardware revision is unlikely to be taken forwards - a different hardware layout is required to support 23128 with the 3rd CS line being used, as well as 32KB and 64KB ROMs.

Some default firmware configuration has been changed:
- BOOT_LOGGING is now disabled by default to improve boot times.

### New

- [Atari 800XL BASIC ROM config](/config/atari800xl.mk) included (and tested and working!)

### Changes

- Call out from sdrr-gen to wget to retrieve images located on sourceforge, as cloudfare seems to spot and block Rust TLS.
- Moved the PCB config/property files from `/hw-config` to `/rust/config/json`.

### Fixes

- Make "no ROMs installed" LED blink pattern slower, to be more visible.  Now on for 0.5s, off for 2.5s.  Previously flashed much too fast to be used properly.

## v0.5.0 - 2025-10-07

This release adds a bunch of hardware revisions, plus a modified flash and firmware format, to ease future device re-programming.

As a consequence of the new flash/firmware format, some of the STM32 variants (F401RB/RC, F411RC, F446RC) support 2 fewer ROM images than before.

### New

- New flash/firmware format, with firmware code, followed by ROM metadata, followed by ROM images. 
- Added One ROM Ice USB H2 (unverified).
- Added One Rom Ice USB H (verified) kicad files.
- Added One ROM Fire USB B (unverified)

### Changes

Moved USB programmer site to https://github.com/piersfinlayson/one-rom-site repo.

## v0.4.4 - 2025-09-30

This is a point release that changes the release artifact generation, to set up the One ROM USB programmer to be able to offer to flash pre-built firmware images from the release artifacts.

Release artifact change summary:
- Include additional hardware variants
- Only include .bin files (not .elf, .dis, .map) in the release artifacts.
- Remove some of the less common STM32 variants from the release artifacts (to save build time and space)
- Include a build artifact manifest JSON file. 

If the particular release artifact you want is no longer included, you can build it yourself from source.

### Changes

Updated:
- USB One ROM site (onerom.piers.rocks):
  - Added the ability to select a local file as the firmware source, in addition to a URL.
  - Add check to prevent non-USB firmware being flashed.
  - Add check to ensure the MCU the firmware was build for matches the MCU the user selected.
- CI build process, to create release artifacts:
  - Now only creates .bin files (not .elf, .dis, .map) - if you want the other types, build them yourself.
  - Creates images for multiple different hardware revisions.

## v0.4.3 - 2025-09-29

Added USB DFU support for firmware updates over USB, along with STM32 24-pin rev H hardware (24-h) which includes a micro-USB connector.  One ROM detects when USB is connected, disables ROM serving, and enters STM32 DFU mode to allow the firmware to be updated.

There is also a new web-based programmer for One ROM USB, at https://onerom.piers.rocks/.  This can be used on Chrome or Chromium based browsers on Windows, Linux, or MacOS to program an attached One ROM USB.

### Changes

Updated:
- sdrr
- sdrr-hw-config
- sdrr-pcb
- sdrr-common
- sdrr-fw-parser
- sdrr-gen
- sdrr-info

### Fixes

## v0.4.2 - 2025-09-06

Added [One ROM Lab](rust/lab/README.md) support, which allows a One ROM to be used as a ROM reader.

### Changes

- Added fw-parser for One ROM Lab
- Modify sdrr-info/parser to support Airfrog custom firmware changes

### Fixes

- Probably a few here and there.

## v0.4.1 - 2025-08-28

### Changes

- Move STM32F4 hardware rev G to verified.
- Add KiCad design files for RP2350 rev A and STM32F4 rev G.

### Fixes

- #8 - reduce severity of VOS not ready warning, as it appears to be benign.
- Include RP2350 images in github release.
- Add RP2350 build commands to README.md and generally update the docs to refer to One ROM/RP2350.

## v0.4.0 - 2025-08-24

**The RP2350 release.**

This version contains the first RP2350 PCB revision, and mostly complete firmware support.

Should you use the new RP2350 hardware revision A?  Only limited testing of the RP2350 One ROM has been done so far, but it has generally performed well.

There is one outstanding, known issue - when using the RP2350 One ROM a character ROM on a PAL VIC-20 occasionally the machine boots to a black screen background - that is the machine boots to BASIC and shows the expected text, but the screen is black, not white.  This may be a boot timing issue - that perhaps One ROM RP2350 is not booting fast enough for the VIC chip, which is getting corrupted somehow.  This issue does not appear on a C64 (which has a different video bus architecture).

You may want to order and test small quantities of RP2350 based boards for now, as there is some risk of a hardware design issue coming to light.  However, the hardware appears solid in early testing, so it is likely most issues can be overcome by firmware changes - and it is expected that the RP2350 revision A will continue to be supported in future releases, even should another variant be released.

Other notable changes:

- Instead of building with `STM=<mcu variant> make`, you now need to use `MCU`:

  ```bash
  MCU=<mcu_variant> make
  ```

### Changes

- Added RP2350 support.
  - Hardware rev A.
  - Includes single ROM images, dynamically bank switched, and multi-ROM sets.
  - Includes image select jumpers, status LED, overclocking.
  - Features not supported include: C main loop, MCO output.
  - For the gory details of supporting the RP2350, see [RP2350](docs/RP2350.md).
- Added STM32F4 24-pin PCB rev G hardware configuration.  This adds a different programming header and one more image select jumper (so 5 in total, plus X1/2).
- Added hardware and firmware configuration to specify whether the image select jumpers and X1/X2 pins are pulled high or low when the PCB jumper is closed, to allow for different PCB designs.
- Added firmware support for up to 7 image select jumpers.
- Change STM32 MCO (and MCO2) divider to be /5 (previous value was /4).  Makes it easier to measure the clock speed of an overclocked STM32F4.
- Substantially refactored platform specific code to break out platform agnostic code - significant work to `sdrr/src/main.c`, `utils.c` and `rom_impl.c`.
- Tested overclocking and various STM32 clones.

### Fixes

- It is likely that the 4th image select pin on revs E/F didn't work properly - this has been fixed.

## v0.3.1 - 2025-08-16

The project has been renamed One ROM (To Rule Them All).

This release is a few odds and ends including some hardware improvements:
- One ROM hardware revision [F2](/sdrr-pcb/verified/stm32f4-24-pin-rev-f2/README.md) is currently recommended.
- An **unverified** hardware revision [G](/sdrr-pcb/unverified/stm32f4-24-pin-rev-g/README.md) is in testing.  This brings mostly layout improvements and slightly reduced manufacturing costs.
- The fastest STM32F4 MCU, the STM32F446 has been verified to work.   This brings a max supported clock speed of 180MHz, and has run stably up to 300MHz in testing.
- The STM32F405 has provided slower than expected (more details below).  It is supported and a decent choice, but the GigaDevices GD32F405 appears to be more performant.

### Changes

- Speed up STM32F405 support:
  - The STM32F405 is under-performant vs the other devices at the same clock speed - needs around 30-40% faster clock speed.
  - Added CCM RAM support for the F405, bringing the uplift in clock speed down to around 15-20%.
  - To disable CCM RAM set `C_EXTRA_FLAGS=-DDISABLE_CCM=1` when building.
  - The STM32F405 is still a decent MCU choice for One ROM, as its max clock speed is 168MHz compared with the F411's 100MHz.  However, users may wish to use the GigaDevices clone GD32F405, which appears to have no performance penalty. 
- Hardware revision 24-f2 is now verified.  JLC have successfully fabbed using the hardware files both STM32F411 and STM32F405 variants.
- Allow more aggressive overclocking (up to 400MHz).
- Validated STM32F446RCT6 (STM32F446RET6 highly likely to work as well).  Successfully tested as C64 char ROM, and verified clock speed of 180MHz (via MCO1 showing 45MHz = SYSCLK/4).  Also overclocked to 300MHz, ran stably.
- Added **unverified** hardware revision 24-g.

### Fixes

- Explicitly prevent COUNT_ROM_ACCESS and C_MAIN_LOOP being configured together, as they are incompatible.
- Fixed ability to run main loop from RAM (this tends to be slower than from flash, so isn't recommended).

## v0.3.0 - 2025-08-12

The main user facing change in this release is the addition of support for remote analysis and co-processing alongside the SDRR device via plug-ins, such as [Airfrog](https://piers.rocks/u/airfrog) - **a tiny $3 probe for ARM devices**.  This allows you to inspect the firmware and runtime state of the SDRR device, and change its configuration and ROM data - **while it is serving ROMs**.

There is also new ROM access counting feature, which causes SDRR to count how times the CS line(s) go active.  This can be extracted and visualised using [Airfrog](https://piers.rocks/u/airfrog) and other SWD probes, to determine how often the ROMs are accessed based on host activity.

ROM Access Graph

The Rust tooling has been substantially refactored to easier to integrate SDRR support in third-party tooling, such as [Airfrog](https://piers.rocks/u/airfrog).  In particular there is [Firmware Parser](rust/sdrr-fw-parser/README.md) crate, which can be used to parse the firmware from a file or running SDRR, and extract information about the configuration, ROM images, and to extract ROM images from the firmware.

### Changes

- TI-99/4A and CoCo2 configurations have been added to the [third-party configs](config/third-party/README.md) directory.  Thanks to [@keronian](https://github.com/keronian) for contributing these.
- Added a C main loop implementation for which GCC produces the assembly/machine code.  This requires a roughly 25% faster clock speed.  Use `EXTRA_C_FLAGS=-DC_MAIN_LOOP` when running `make` to use this version.
- Stored off image files used to create the firmware in `output/images/`.  This allows post build inspection of the images used.  It also enables additional tests - `sdrr-info` can be now be used as an additional automated check (along with `test`), to ensure the images in the firmware are correct, and validate the behaviour of `sdrr-info` and `test` to be compared.
- Substantial refactoring of `sdrr-gen`, to make it more maintainable.
- Substantial refactoring of `sdrr-fw-parser` in order to make it suitable for airfrog integration.
- Added ROM access counting behind COUNT_ROM_ACCESS feature flag.  When enabled, the firmware updates a u32 counter at RAM address 0x20000008 every time the chip select line(s) go active - i.e. the ROM is selected.  This can be read by an SWD probe, such as [Airfrog](https://piers.rocks/u/sdrr). 
- Changed default Makefile configuration to HW_REV=24-f COUNT_ROM_ACCESS=1 STATUS_LED=1.
- Added a manufacturing test tool [`sdrr-check`](rust/sdrr-check/README.md).
- Changed default build config:
  - HW_REV=24-f
  - STATUS_LED=1
  - COUNT_ROM_ACCESS=1
- Added retrieval of mangled ROM images from firmware.  This can be used to compare the embedded images between different firmwares and to collect a pre-mangled ROM images in order to overwrite a running SDRR's RAM image with it.
- Added new "One ROM To Rule Them All" BASIC program for upcoming video. 

### Fixes

- Probably a few here and there.

## v0.2.1 - 2025-07-22

The main new feature in this version of SDRR is the addition of dynamic [bank switching](docs/MULTI-ROM-SETS.md#dynamic-bank-switching) of ROM images.  This allows SDRR to hold up to 4 different ROM images in RAM, and to switch between them **while the host is running** by using the X1/X2 pins (hardware revision F and later) to switch between them.  Some fun [C64](config/bank-c64-char-fun.mk) and [VIC-20](config/bank-vic20-char-fun.mk) character ROM configurations that support bank switching are included.

In other news:
- The default ROM serving algorithm has been improved, leading to better performance, and hence the ability to support more systems with lower powered STM32F4 devices than before.  Check out [STM32 Selection](docs/STM32-SELECTION.md). The current price/performance sweet spot is the F411.
- [Hardware revision E](sdrr-pcb/verified/stm32f4-24-pin-rev-e/README.md) is now fully verified, so manufacture these with confidence.
- If you'd rather use [revision F](sdrr-pcb/unverified/stm32f4-24-pin-rev-f/README.md) (required for multi-ROM and bank switching support), at least once user has reported getting these manufactured and working with his NTSC VIC-20 - although they did not testing either multi-ROM or bank switching support.

### Changes

- Added pull-up/downs to X1/X2 in multi-ROM cases, so that when a multi-set ROM is configured, but X1/X2 are not connected, the other ROMs in the set still serve properly.
- Improved serving algorithm `B` in the CS active low case.
- Moved to algorithm `B` by default.
- Measured performance of both algorithm on all targets.
- Refactor `rom_impl.c`, breaking out assembly code to `rom_asm.h` to make the main_loop easier to read, and commonalising a bunch of the code for greater maintainability.
- Added detection of hardware reported STM32F4 device and flash size at runtime, and comparison to firmware values - warning logs are produced in event of a mismatch.
- Verified [hw revision e](/sdrr-pcb/verified/stm32f4-24-pin-rev-e/) - supports STM32F4x5 variants in addition to F401/F411, all passives are now 0603, contains a status LED and a 4th image select jumper.
- Added [documentation](/docs/STM32-CLONES.md) on STM32 clones.
- Moved firmware parsing to [`rust/sdrr-fw-parser`](/rust/sdrr-fw-parser/README.md) crate, which can be used to parse the firmware and extract information about the configuration, ROM images, and to extract ROM images from the firmware.  Done in preparation for using the same code from a separate MCU.
- Moved Rust code to [`rust/`](/rust/) directory to declutter the repo a bit.
- Added experimenta; [build containers](/ci/docker/README.md) to assist with building SDRR, and doing so with the recommended build environment.
- Added dynamic [bank switchable](docs/MULTI-ROM-SETS.md#dynamic-bank-switching) ROM image support, using X1/X2 (you can use __either__ multi-ROM __or__ bank switching in a particular set).
- Added fun banked character ROM configs.
- Added VIC-20 NTSC config.
- Added retry in [ci/build.sh](ci/build.sh) to allow for intermittent network issues when downloading dependencies.
- Added [demo programs](demo/README.md) for C64 and VIC-20 to list SDRR features and other information/

### Fixes

- Fixed status LED behaviour, by placing outside of MAIN_LOOP_ONE_SHOT, and using the configured pin.
- Got `sdrr` firmware working on STM32F401RB/RC variants.  These have 64KB RAM, so can only support individual ROM images (quantity limited by flash) and do not support banked or multi-set ROMs.

## v0.2.0 - 2025-07-13

This version brings substantial improvements to the SDRR project, including:

- A single SDRR can be used to replace multiple ROM chips simultaneously.
- New [`sdrr-info`] tool to extract details and ROM images from firmware.
- Add your own hardware configurations, by adding a simple JSON file.
- New STM32F4 variants supported.
- Comprehensive testing of compiled in images to ensure veracity.

Care has been taken to avoid non-backwards compatible interface (such as CLI) changes, but some may may have been missed.  If you find any, please report them as issues.

### New Features

- Added support for ROM sets, allowing SDRR to serve multiple ROM images simultaneously, for certain combinations of ROM types.  This is done by connecting just the chip selects from other, empty sockets to be served, to pins X1/X2 (hardware revision 24-f onwards).  Currently tested only on VIC-20 (PAL) and C64 (PAL), serving kernal and BASIC ROMs simultaneously on VIC-20 and kernal/BASIC/character ROMs simultaneously on the C64.  See [Multi-ROM Sets](/docs/MULTI-ROM-SETS.md) for more details.
- Added [`sdrr-info`](/rust/sdrr-info/README.md) tool to parse the firmware and extract information about the configuration, ROM images, and to extract ROM images from the firmware.  In particular this allows
  - listing which STM32F4 device the firmware was built for
  - extraction of ROM images from the firmware, for checksumming and/or comparing with the originals.
- Moved hardware configuration to a dynamic model, where the supported hardware configurations are defined in configuration files, and the desired version is selected at build time.  Users can easily add configurations for their own PCB layouts, and either submit pull requests to include them in the main repository, or keep them locally.  For more details see [Custom Hardware](/docs/CUSTOM-HARDWARE.md).
- Added support F446 STM32F446R C/E variants - max clock speed 180 MHz (in excess of the F405's 168 MHz).  Currently untested.
- Added [`test`](/test/README.md), to verify the images source code files which are built into the firmware image, output the correct bytes, given the mangling that has taken place.

### Changes

- Updated VIC-20 PAL config to use VIC-20 dead-test v1.1.01.
- 24-pin PCB rev E/F gerbers provided (as yet unverified).
- Many previously compile time features now moved to runtime.
- Makefile produces more consistent and less verbose output.
- Added `sddr_info` struct to main firmware, containing firmware properties, for use at runtime, and later extraction.  This should also allow querying the firmware of a running system via SWD in future.

### Fixed

- Moved to fast speed outputs for data lines, instead of high speed, to ensure VOL is 0.4V, within the 6502's 0.8V requirement.  With high speed outputs, the VOL can be as high as 1.3V, which is beyond the 6502's 0.8V requirement.

## v0.1.0 - 2025-06-29

First release of SDRR.

- Supports F401, F411, and F405 STM32F4xxR variants.
- Includes configurations and pre-built firmware for C64, VIC-20 PAL, PET, 1541 disk drive, and IEEE disk drives.
- PCB rev D design included.
- Release binaries

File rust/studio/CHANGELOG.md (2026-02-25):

# Changelog

## v0.1.15 - 2026-02-25

- Added 2704/2708 ROM support.
- Added prototype One ROM 32 support (27C010, 27C020, 27C040, 27C301 and 27C080 via stacked One ROM 32s).

## v0.1.14 - 2026-02-22

- Fixed #152 (Studio fails to flash large images to One ROM 40 ROMs)

## v0.1.13 - 2026-02-22

Adds One ROM 40 ROM support.

## v0.1.12

## v0.1.11 - 2026-02-3

- Add some keyboard shortcuts to One ROM Studio:
  - r: Rescan devices
  - f: Flash firmware
- Added 231024 support.

## v0.1.9 - 2026-01-22

### Fixed

- Fixed #90 in v0.6.0 when older (pre v0.1.8) versions of One ROM Studio are used to build firmware images with more than one ROM set, One ROM will not boot on any ROM set other than ROM set 0.
- 2732 ROM type serving was broken - the top 2K replicated the bottom 2K.  Fixed (#103).  This included fixing the testing, which had also not caught this issue.

## v0.1.8 - 2026-01-14

### Added

- Support for low level config of firmware at runtime using JSON files #87.

## v0.1.7 - 2026-01-03

### Added

- #77 - Support for serving multi-ROM sets using Fire PIO algorithm.

## v0.1.6 - 2026-01-01

### Added

- 231024 ROM support in JSON config files.
- fire-24-c
- ice-24-i

## v0.1.5 - 2025-12-12

### Added

- fire-28-a

## v0.1.4 - 2025-12-09

### Added

- Support for local files to onerom-fw and onerom-studio.

### Fixed

- Set Windows PE file and product versions to match Cargo version.

## v0.1.3 - 2025-11-24

### Fixed

- Panic (crash) when analyzing a Fire with a debug probe.  Moved to fork of probe-rs with fix for panic.
- Allow multi-rom sets to be built
- Statically link with vcruntime

## v0.1.2 - 2025-11-09

- Built with rustc 1.91
- Move to probe-rs 0.30
- Added ability to load ROM config JSON files from disk in Create view
- Added online manifest to access latest URLs, with local cache file backup, and defaults as further backup
- Added app version update check and download link

## v0.1.1 - 2025-10-30

- Built with rustc 1.90
- Mac and Windows releases now signed.
- Mac app now uses the One ROM liquid glass icon.
- Moved to libusb-less DFU implementation using `dfu-rs` and `nusb` crates.
- Moved to manual rescanning to detect probes and USB devices.
- Added network connectivity icon.
- Single universal macOS dmg installer instead of separate Intel and Apple Silicon versions.
- Added ability to load ROM config JSON files from disk in Create view.

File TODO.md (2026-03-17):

* [ ] Implement optional link to work with [Amiga 500 Rev 5](https://theoasisbbs.com/permanent-fix-for-the-amiga-500-rev-5-oops-bug/)

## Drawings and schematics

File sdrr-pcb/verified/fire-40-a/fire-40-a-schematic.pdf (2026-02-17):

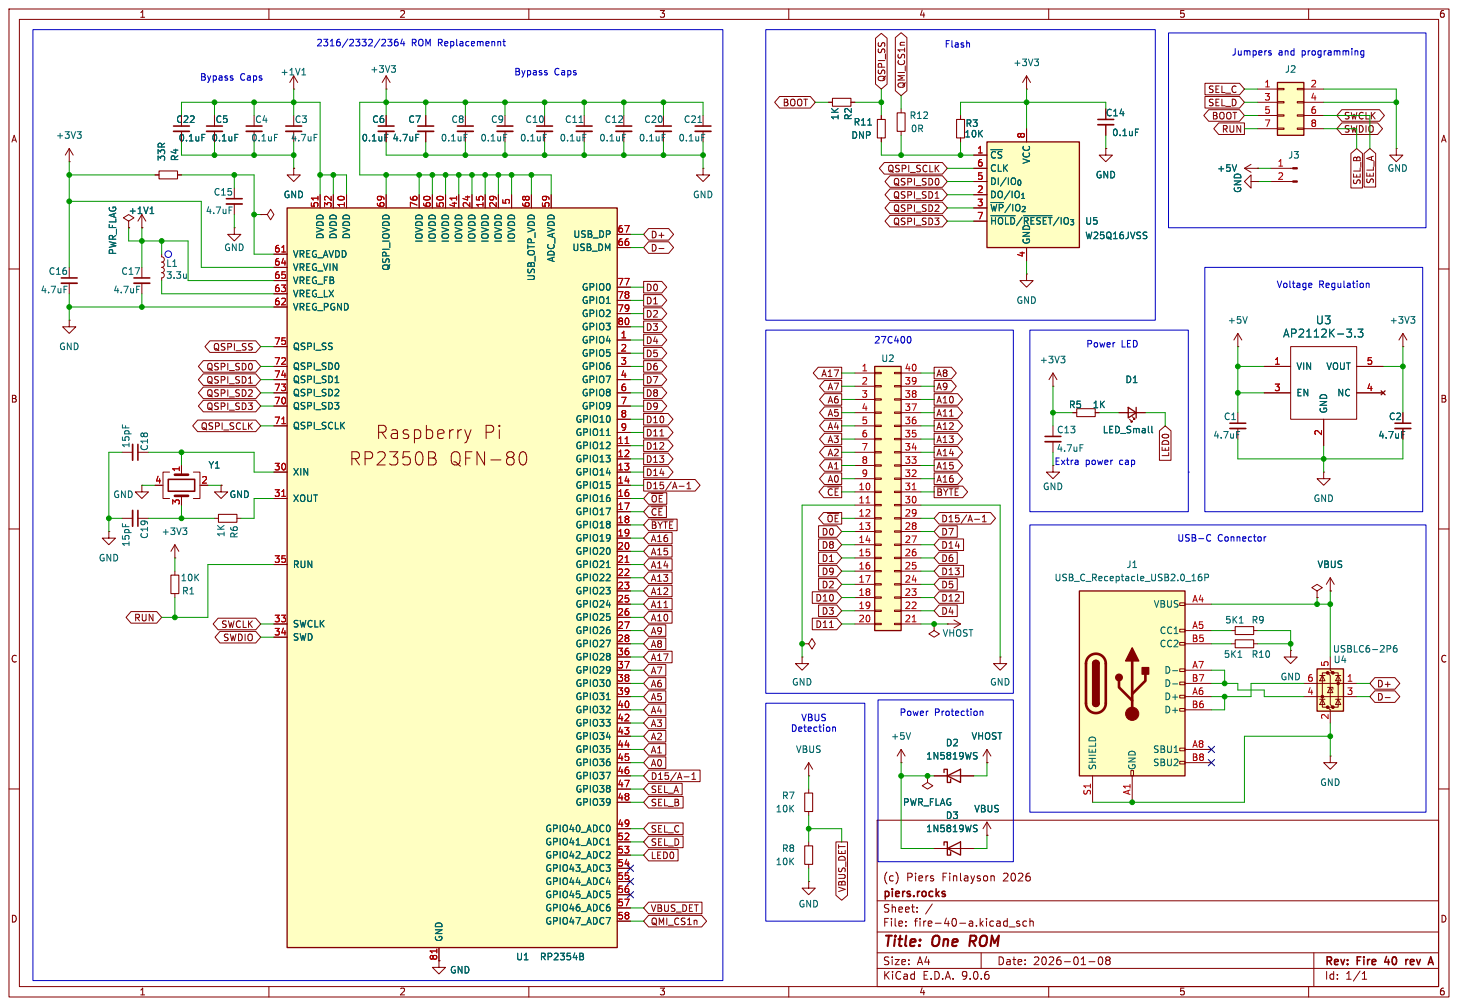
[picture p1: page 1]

2 VOUT 5 NC 4 VBUS GND

File: fire-40-a.kicad_sch Sheet: / piers.rocks

Id: 1/1 Title: One ROM

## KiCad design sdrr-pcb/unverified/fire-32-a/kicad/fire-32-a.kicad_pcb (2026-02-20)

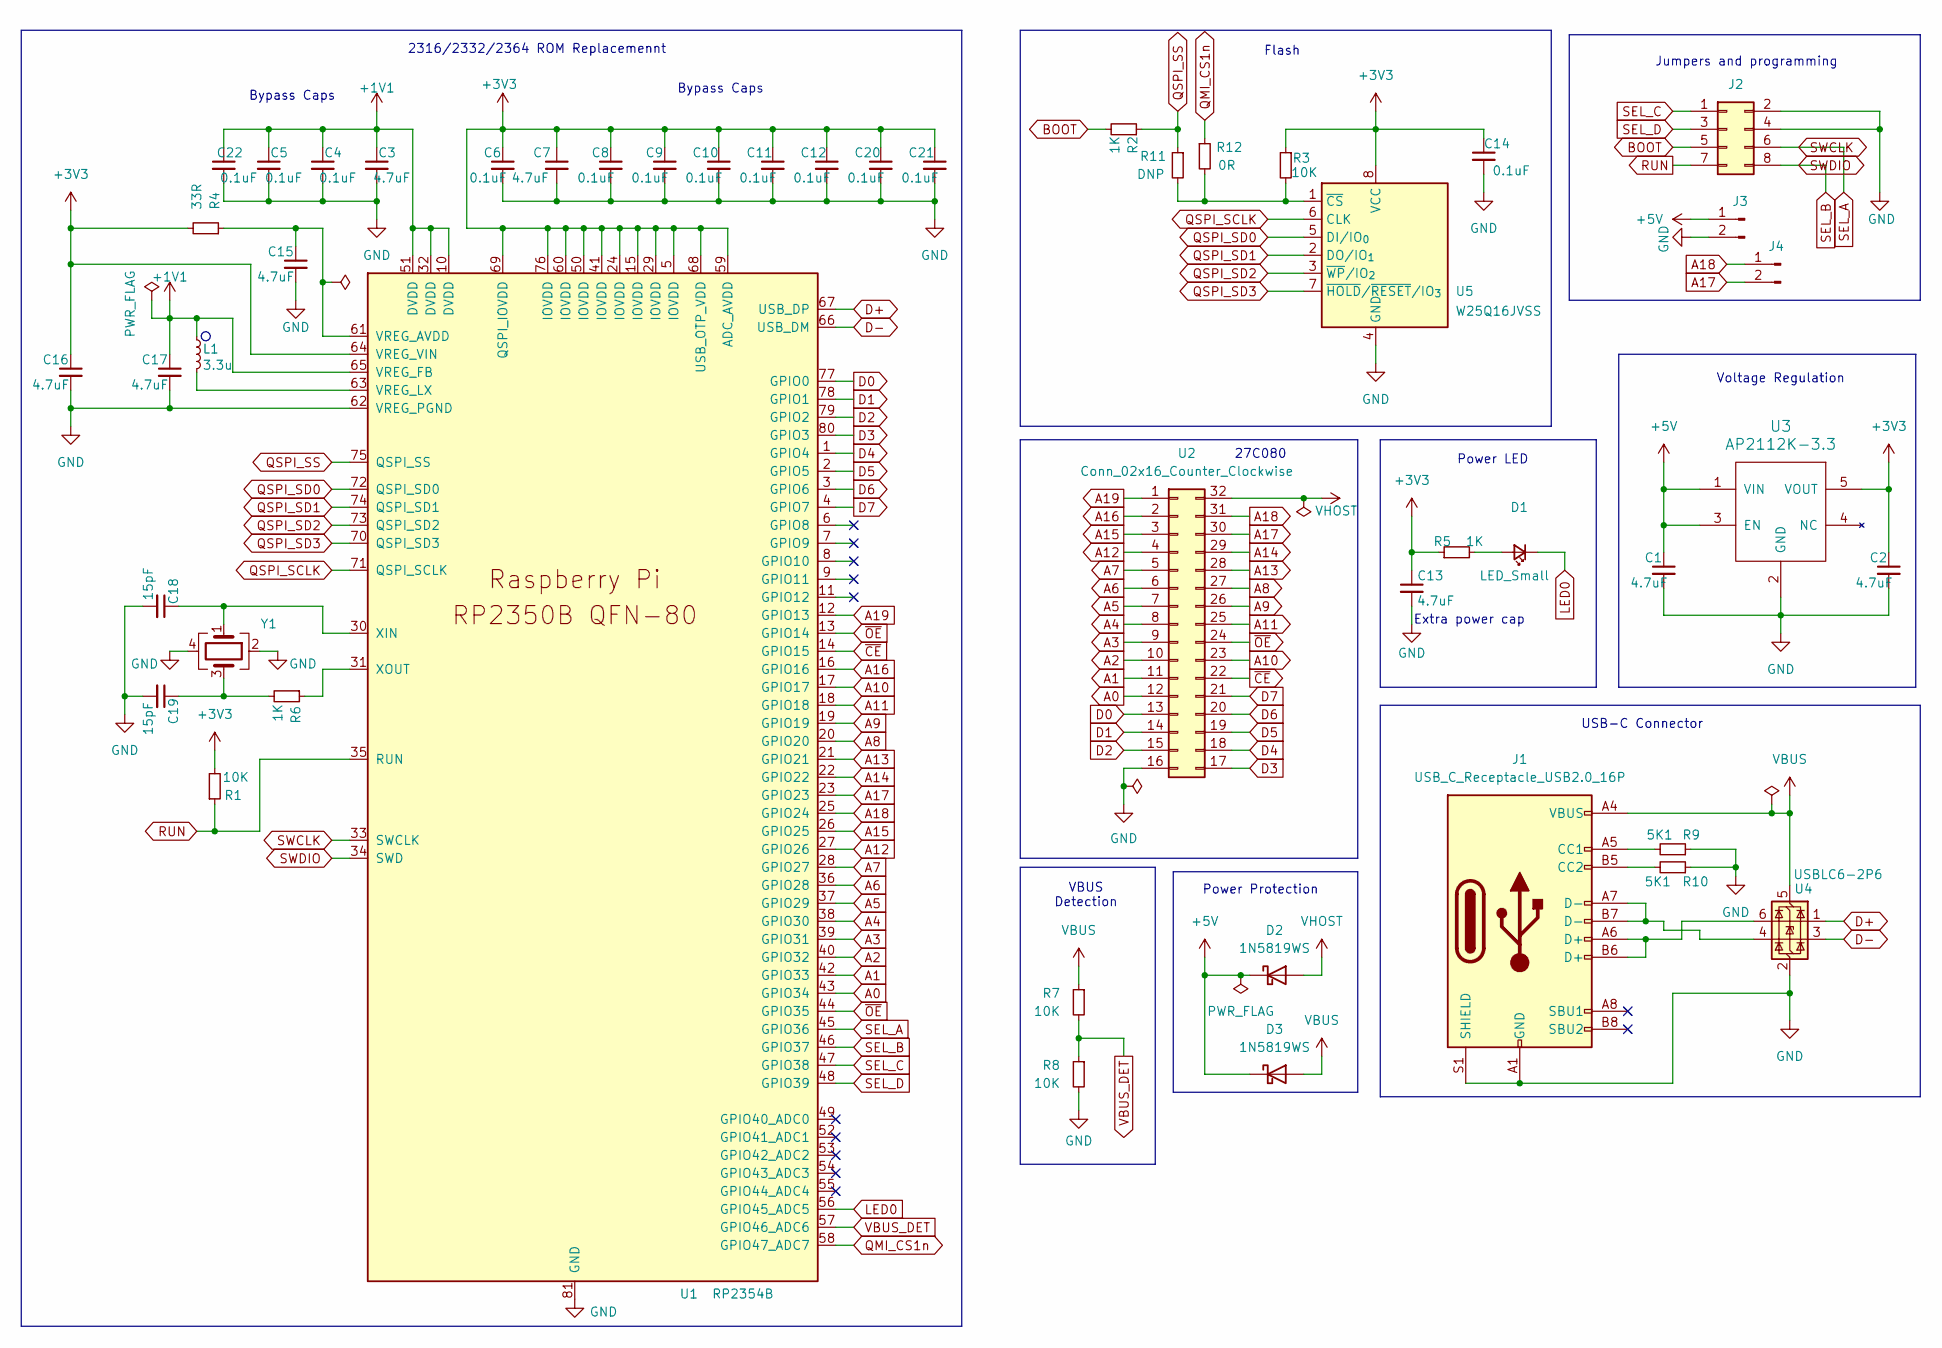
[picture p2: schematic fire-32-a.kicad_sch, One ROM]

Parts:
C1, C2, C3, C7, C13, C15: 4.7uF; C_0402_1005Metric; LCSC C23733
C4, C5, C6, C8, C9, C10, C11, C12, C14, C20, C21, C22: 0.1uF; C_0402_1005Metric; LCSC C1525
C16, C17: 4.7uF; C_0402_1005Metric_small_pads; LCSC C23733
C18, C19: 15pF; C_0402_1005Metric; LCSC C1548
D1: LED_Small; LED_0402_1005Metric; LCSC C25503345
D2, D3: 1N5819WS; D_SOD-323; LCSC C191023
J1: USB_C_Receptacle_USB2.0_16P; USB_C_connector_c2765186; LCSC C2765186
J2: Conn_02x04_Odd_Even; PinHeader_2x04_P2.54mm_Vertical custom silkscreen
J3, J4: Conn_01x02_Pin; PinHeader_1x02_P2.54mm_Vertical
L1: 3.3u; L_pol_2016; LCSC C42411119
R1, R3, R7, R8: 10K; R_0402_1005Metric; LCSC C25744
R2, R5, R6: 1K; R_0402_1005Metric; LCSC C11702
R4: 33R; R_0402_1005Metric; LCSC C25105
R9, R10: 5K1; R_0402_1005Metric; LCSC C25905
R11: DNP; R_0402_1005Metric; LCSC C17168
R12: 0R; R_0402_1005Metric; LCSC C17168
U1: RP2354B; RP2350-QFN-80-1EP_10x10_P0.4mm_EP3.4x3.4mm_ThermalVias; LCSC C39843328
U2: Conn_02x16_Counter_Clockwise; one rom 32 output
U3: AP2112K-3.3; SOT-23-5; LCSC C51118
U4: USBLC6-2P6; SOT-666; LCSC C15999
U5: W25Q16JVSS; Winbond_USON-8-1EP_3x2mm_P0.5mm_EP0.2x1.6mm; LCSC C2843335
Y1: Crystal_GND24; Crystal_SMD_Abracon_ABM8G-4Pin_3.2x2.5mm; LCSC C20625731

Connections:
+1V1: C3.1, C4.1, C5.1, C17.1, C22.1, L1.1, U1.10 (DVDD), U1.32 (DVDD), U1.51 (DVDD), U1.65 (VREG_FB)
+3V3: C2.1, C6.1, C7.1, C8.1, C9.1, C10.1, C11.1, C12.1, C13.1, C14.1, C16.1, C20.1, C21.1, R1.2, R3.1, R4.2, R5.1, U1.5 (IOVDD), U1.15 (IOVDD), U1.24 (IOVDD), U1.29 (IOVDD), U1.41 (IOVDD), U1.50 (IOVDD), U1.59 (ADC_AVDD), U1.60 (IOVDD), U1.64 (VREG_VIN), U1.68 (USB_OTP_VDD), U1.69 (QSPI_IOVDD), U1.76 (IOVDD), U3.5 (VOUT), U5.8 (VCC)
+5V: C1.1, D2.1 (K), D3.1 (K), J3.1, U3.1 (VIN), U3.3 (EN)
A0: U1.43 (GPIO34), U2.12
A1: U1.42 (GPIO33), U2.11
A2: U1.40 (GPIO32), U2.10
A3: U1.39 (GPIO31), U2.9
A4: U1.38 (GPIO30), U2.8
A5: U1.37 (GPIO29), U2.7
A6: U1.36 (GPIO28), U2.6
A7: U1.28 (GPIO27), U2.5
A8: U1.20 (GPIO20), U2.27
A9: U1.19 (GPIO19), U2.26
A10: U1.17 (GPIO17), U2.23
A11: U1.18 (GPIO18), U2.25
A12: U1.27 (GPIO26), U2.4
A13: U1.21 (GPIO21), U2.28
A14: U1.22 (GPIO22), U2.29
A15: U1.26 (GPIO25), U2.3
A16: U1.16 (GPIO16), U2.2
A17: J4.2, U1.23 (GPIO23), U2.30
A18: J4.1, U1.25 (GPIO24), U2.31
A19: U1.12 (GPIO13), U2.1
BOOT: J2.5, R2.2
D0: U1.77 (GPIO0), U2.13
D1: U1.78 (GPIO1), U2.14
D2: U1.79 (GPIO2), U2.15
D3: U1.80 (GPIO3), U2.17
D4: U1.1 (GPIO4), U2.18
D5: U1.2 (GPIO5), U2.19
D6: U1.3 (GPIO6), U2.20
D7: U1.4 (GPIO7), U2.21
D+: U1.67 (USB_DP), U4.1 (I/O1)
D-: U1.66 (USB_DM), U4.3 (I/O2)
GND: C1.2, C2.2, C3.2, C4.2, C5.2, C6.2, C7.2, C8.2, C9.2, C10.2, C11.2, C12.2, C13.2, C14.2, C15.2, C16.2, C17.2, C18.2, C19.2, C20.2, C21.2, C22.2, J1.A1 (GND), J1.A12 (GND), J1.B1 (GND), J1.B12 (GND), J1.S1 (SHIELD), J2.2, J2.4, J3.2, R8.2, R9.1, R10.1, U1.62 (VREG_PGND), U1.81 (GND), U2.16, U3.2 (GND), U4.2 (GND), U5.4 (GND), Y1.2, Y1.4
LED0: D1.1 (K), U1.56 (GPIO45_ADC5)
unnamed: C19.1, R6.2, Y1.3
unnamed: D1.2 (A), R5.2
unnamed: J1.A5 (CC1), R9.2
unnamed: J1.B5 (CC2), R10.2
unnamed: J1.A6 (D+), J1.B6 (D+), U4.6 (I/O1)
unnamed: J1.A7 (D-), J1.B7 (D-), U4.4 (I/O2)
unnamed: C15.1, R4.1, U1.61 (VREG_AVDD)
unnamed: L1.2, U1.63 (VREG_LX)
unnamed: C18.1, U1.30 (XIN), Y1.1
unnamed: R6.1, U1.31 (XOUT)
unnamed: R3.2, R11.2, R12.2, U5.1 (~CS)
QMI_CS1n: R12.1, U1.58 (GPIO47_ADC7)
QSPI_SCLK: U1.71 (QSPI_SCLK), U5.6 (CLK)
QSPI_SD0: U1.72 (QSPI_SD0), U5.5 (DI/IO_{0})
QSPI_SD1: U1.74 (QSPI_SD1), U5.2 (DO/IO_{1})
QSPI_SD2: U1.73 (QSPI_SD2), U5.3 (~WP/IO_{2})
QSPI_SD3: U1.70 (QSPI_SD3), U5.7 (~HOLD/~RESET/IO_{3})
QSPI_SS: R2.1, R11.1, U1.75 (QSPI_SS)
RUN: J2.7, R1.1, U1.35 (RUN)
SEL_A: J2.6, U1.33 (SWCLK), U1.45 (GPIO36)
SEL_B: J2.8, U1.34 (SWD), U1.46 (GPIO37)
SEL_C: J2.1, U1.47 (GPIO38)
SEL_D: J2.3, U1.48 (GPIO39)
VBUS: D3.2 (A), J1.A4 (VBUS), J1.A9 (VBUS), J1.B4 (VBUS), J1.B9 (VBUS), R7.1, U4.5 (VBUS)
VBUS_DET: R7.2, R8.1, U1.57 (GPIO46_ADC6)
VHOST: D2.2 (A), U2.32
~CE: U1.14 (GPIO15), U2.22
~OE: U1.13 (GPIO14), U1.44 (GPIO35), U2.24

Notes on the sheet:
USB-C Connector
Voltage Regulation
Extra power cap
2316/2332/2364 ROM Replacemennt
Bypass Caps
Power LED
Power Protection
27C080
VBUS Detection
Flash
Jumpers and programming

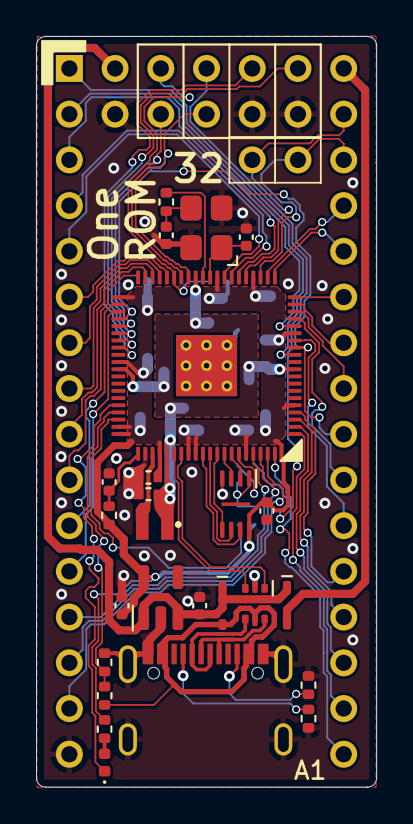
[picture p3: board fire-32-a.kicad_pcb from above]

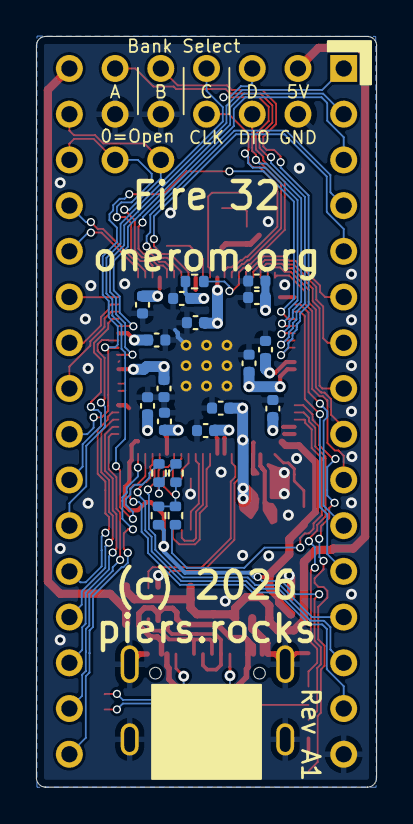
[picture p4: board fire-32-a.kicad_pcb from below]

Board: 2 copper layers, 18.9 x 41.7 mm, 48 parts (19 on the bottom side), 64 nets.

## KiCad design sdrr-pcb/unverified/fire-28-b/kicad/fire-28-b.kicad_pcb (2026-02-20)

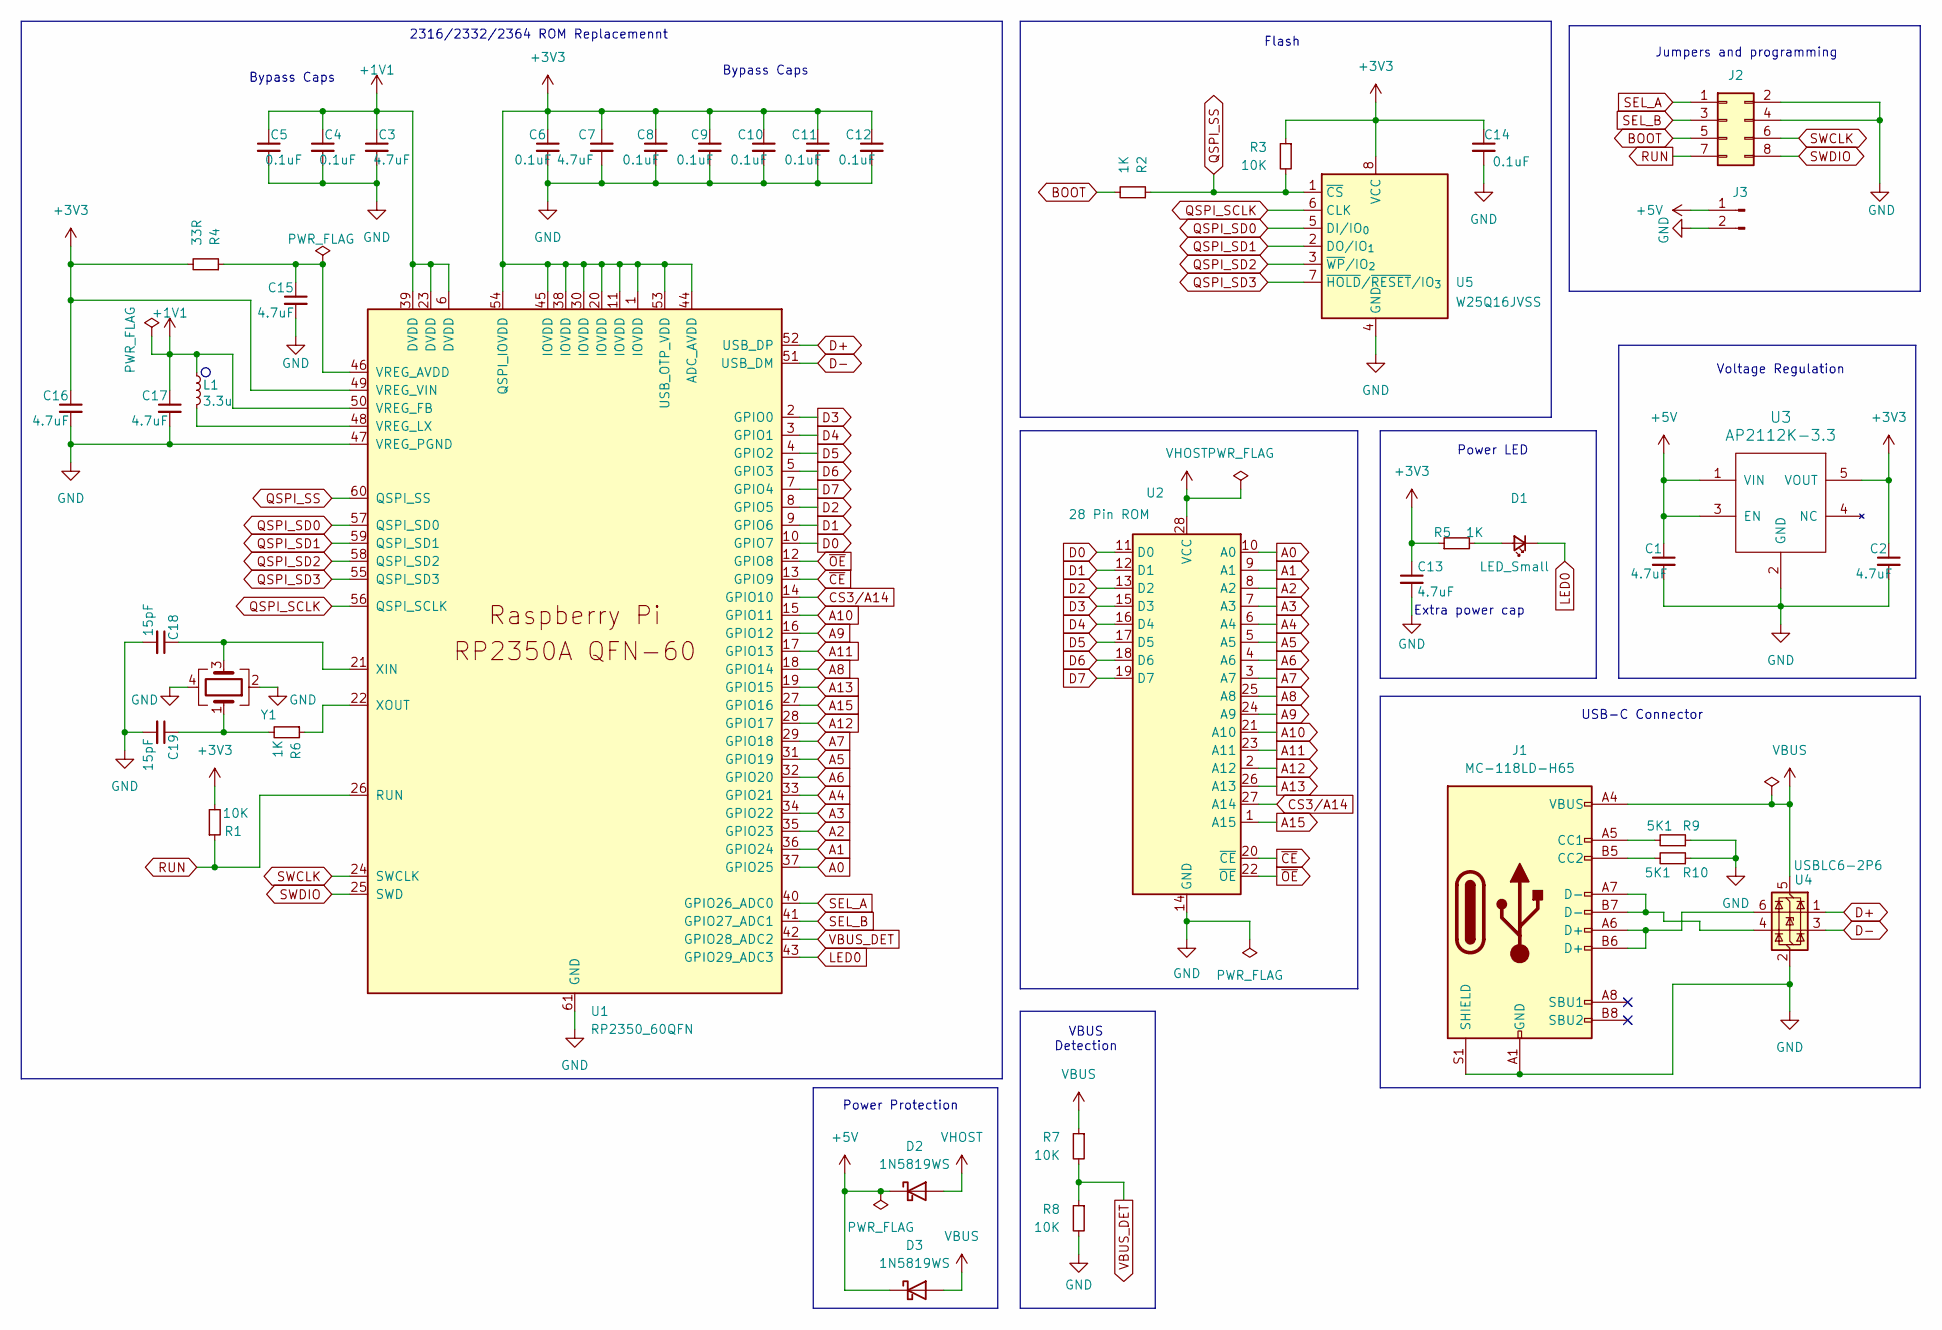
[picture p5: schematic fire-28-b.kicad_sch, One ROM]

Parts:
C1, C2, C3, C7, C13, C15: 4.7uF; C_0402_1005Metric; LCSC C23733
C4, C5, C6, C8, C9, C10, C11, C12, C14: 0.1uF; C_0402_1005Metric; LCSC C1525
C16, C17: 4.7uF; C_0402_1005Metric_small_pads; LCSC C23733
C18, C19: 15pF; C_0402_1005Metric; LCSC C1548
D1: LED_Small; LED_0603_1608Metric; LCSC C2286
D2, D3: 1N5819WS; D_SOD-323; LCSC C191023
J1: MC-118LD-H65; USB-C-upright-C6332304-hanbo-MC-118LD-H65; LCSC C6332304
J2: Conn_02x04_Odd_Even; PinHeader_2x04_P2.54mm_Vertical custom silkscreen
J3: Conn_01x02_Pin; PinHeader_1x02_P2.54mm_Vertical
L1: 3.3u; L_pol_2016; LCSC C42411119
R1, R3, R7, R8: 10K; R_0402_1005Metric; LCSC C25744
R2, R5, R6: 1K; R_0402_1005Metric; LCSC C11702
R4: 33R; R_0402_1005Metric; LCSC C25105
R9, R10: 5K1; R_0402_1005Metric; LCSC C25905
U1: RP2350_60QFN; RP2350-QFN-60-1EP_7x7_P0.4mm_EP3.4x3.4mm_ThermalVias; LCSC C42411118
U2: 28 Pin ROM; 28 pin rom footprint
U3: AP2112K-3.3; SOT-23-5; LCSC C51118
U4: USBLC6-2P6; SOT-666; LCSC C15999
U5: W25Q16JVSS; Winbond_USON-8-1EP_3x2mm_P0.5mm_EP0.2x1.6mm; LCSC C2843335
Y1: Crystal_GND24; Crystal_SMD_Abracon_ABM8G-4Pin_3.2x2.5mm; LCSC C20625731

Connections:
+1V1: C3.1, C4.1, C5.1, C17.1, L1.1, U1.6 (DVDD), U1.23 (DVDD), U1.39 (DVDD), U1.50 (VREG_FB)
+3V3: C2.1, C6.1, C7.1, C8.1, C9.1, C10.1, C11.1, C12.1, C13.1, C14.1, C16.1, R1.2, R3.1, R4.2, R5.1, U1.1 (IOVDD), U1.11 (IOVDD), U1.20 (IOVDD), U1.30 (IOVDD), U1.38 (IOVDD), U1.44 (ADC_AVDD), U1.45 (IOVDD), U1.49 (VREG_VIN), U1.53 (USB_OTP_VDD), U1.54 (QSPI_IOVDD), U3.5 (VOUT), U5.8 (VCC)
+5V: C1.1, D2.1 (K), D3.1 (K), J3.1, U3.1 (VIN), U3.3 (EN)
A0: U1.37 (GPIO25), U2.10 (A0)
A1: U1.36 (GPIO24), U2.9 (A1)
A2: U1.35 (GPIO23), U2.8 (A2)
A3: U1.34 (GPIO22), U2.7 (A3)
A4: U1.33 (GPIO21), U2.6 (A4)
A5: U1.31 (GPIO19), U2.5 (A5)
A6: U1.32 (GPIO20), U2.4 (A6)
A7: U1.29 (GPIO18), U2.3 (A7)
A8: U1.18 (GPIO14), U2.25 (A8)
A9: U1.16 (GPIO12), U2.24 (A9)
A10: U1.15 (GPIO11), U2.21 (A10)
A11: U1.17 (GPIO13), U2.23 (A11)
A12: U1.28 (GPIO17), U2.2 (A12)
A13: U1.19 (GPIO15), U2.26 (A13)
A15: U1.27 (GPIO16), U2.1 (A15)
BOOT: J2.5, R2.2
CS3/A14: U1.14 (GPIO10), U2.27 (A14)
D0: U1.10 (GPIO7), U2.11 (D0)
D1: U1.9 (GPIO6), U2.12 (D1)
D2: U1.8 (GPIO5), U2.13 (D2)
D3: U1.2 (GPIO0), U2.15 (D3)
D4: U1.3 (GPIO1), U2.16 (D4)
D5: U1.4 (GPIO2), U2.17 (D5)
D6: U1.5 (GPIO3), U2.18 (D6)
D7: U1.7 (GPIO4), U2.19 (D7)
D+: U1.52 (USB_DP), U4.1 (I/O1)
D-: U1.51 (USB_DM), U4.3 (I/O2)
GND: C1.2, C2.2, C3.2, C4.2, C5.2, C6.2, C7.2, C8.2, C9.2, C10.2, C11.2, C12.2, C13.2, C14.2, C15.2, C16.2, C17.2, C18.2, C19.2, J1.A1 (GND), J1.A12 (GND), J1.B1 (GND), J1.B12 (GND), J1.S1 (SHIELD), J2.2, J2.4, J3.2, R8.2, R9.1, R10.1, U1.47 (VREG_PGND), U1.61 (GND), U2.14 (GND), U3.2 (GND), U4.2 (GND), U5.4 (GND), Y1.2, Y1.4
LED0: D1.1 (K), U1.43 (GPIO29_ADC3)
unnamed: C19.1, R6.2, Y1.1
unnamed: D1.2 (A), R5.2
unnamed: J1.A5 (CC1), R9.2
unnamed: J1.B5 (CC2), R10.2
unnamed: J1.A6 (D+), J1.B6 (D+), U4.6 (I/O1)
unnamed: J1.A7 (D-), J1.B7 (D-), U4.4 (I/O2)
unnamed: C15.1, R4.1, U1.46 (VREG_AVDD)
unnamed: L1.2, U1.48 (VREG_LX)
unnamed: C18.1, U1.21 (XIN), Y1.3
unnamed: R6.1, U1.22 (XOUT)
QSPI_SCLK: U1.56 (QSPI_SCLK), U5.6 (CLK)
QSPI_SD0: U1.57 (QSPI_SD0), U5.5 (DI/IO_{0})
QSPI_SD1: U1.59 (QSPI_SD1), U5.2 (DO/IO_{1})
QSPI_SD2: U1.58 (QSPI_SD2), U5.3 (~WP/IO_{2})
QSPI_SD3: U1.55 (QSPI_SD3), U5.7 (~HOLD/~RESET/IO_{3})
QSPI_SS: R2.1, R3.2, U1.60 (QSPI_SS), U5.1 (~CS)
RUN: J2.7, R1.1, U1.26 (RUN)
SEL_A: J2.1, U1.40 (GPIO26_ADC0)
SEL_B: J2.3, U1.41 (GPIO27_ADC1)
SWCLK: J2.6, U1.24 (SWCLK)
SWDIO: J2.8, U1.25 (SWD)
VBUS: D3.2 (A), J1.A4 (VBUS), J1.A9 (VBUS), J1.B4 (VBUS), J1.B9 (VBUS), R7.1, U4.5 (VBUS)
VBUS_DET: R7.2, R8.1, U1.42 (GPIO28_ADC2)
VHOST: D2.2 (A), U2.28 (VCC)
~CE: U1.13 (GPIO9), U2.20 (~CE)
~OE: U1.12 (GPIO8), U2.22 (~OE)

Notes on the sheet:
USB-C Connector
Voltage Regulation
Extra power cap
2316/2332/2364 ROM Replacemennt
Bypass Caps
Power LED
Power Protection
VBUS Detection
Flash
Jumpers and programming

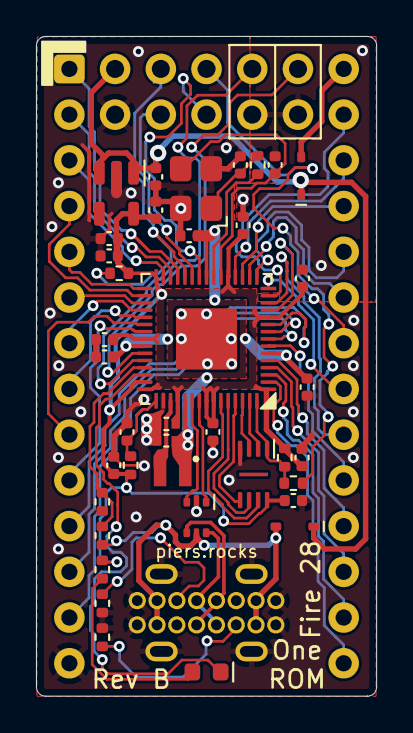
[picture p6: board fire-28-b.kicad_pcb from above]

Board: 2 copper layers, 18.9 x 36.7 mm, 42 parts (0 on the bottom side), 58 nets.

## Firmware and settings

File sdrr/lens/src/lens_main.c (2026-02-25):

// Copyright (C) 2026 Piers Finlayson <piers@piers.rocks>
//
// MIT License

// One ROM WASM API

// Causes declarations in stubbed out code, so One ROM firmware compiles
#define TEST_MAIN_C

#include <stdio.h>
#include <include.h>
#include "roms.h"
#include <test/stub.h>
#include <apio.h>
#include <epio.h>
#include <epio_wasm.h>

static epio_t *g_epio = NULL;
static uint8_t addr_pins[32];
static uint8_t data_pins[16];
static uint8_t cs1_pin, cs2_pin, cs3_pin, x1_pin, x2_pin, ce_pin, oe_pin, byte_pin;

static const sdrr_rom_info_t *get_first_rom_info(void) {
    if (sdrr_rom_set_count == 0) {
        return NULL; // No ROM sets available
    }

    // Get the first ROM image
    const sdrr_rom_set_t *rom_set_0 = &rom_set[0];
    if (rom_set_0->rom_count == 0) {
        return NULL; // No ROMs in the set
    }

    return rom_set_0->roms[0];
}

EPIO_EXPORT sdrr_rom_type_t onerom_lens_get_rom_type(void) {
    const sdrr_rom_info_t *rom = get_first_rom_info();
    if (!rom) {
        return INVALID_CHIP_TYPE; // No ROM available
    }
    return rom->rom_type;
}

static void setup_pin_mappings(void) {
    // Address pins
    for (int ii = 0; ii < 16; ii++) {
        addr_pins[ii] = sdrr_info.pins->addr[ii];
    }
    for (int ii = 0; ii < 8; ii++) {
        addr_pins[16 + ii] = sdrr_info.pins->addr2[ii];
    }
    
    // Data pins
    for (int ii = 0; ii < 8; ii++) {
        data_pins[ii] = sdrr_info.pins->data[ii];
    }
    for (int ii = 0; ii < 8; ii++) {
        data_pins[8 + ii] = sdrr_info.pins->data2[ii];
    }
    
    // Control pins
    cs1_pin = sdrr_info.pins->cs1;
    cs2_pin = sdrr_info.pins->cs2;
    cs3_pin = sdrr_info.pins->cs3;
    x1_pin = sdrr_info.pins->x1;
    x2_pin = sdrr_info.pins->x2;
    ce_pin = sdrr_info.pins->ce;
    oe_pin = sdrr_info.pins->oe;
    byte_pin = sdrr_info.pins->byte;

    if ((onerom_lens_get_rom_type() == CHIP_TYPE_27C400) && (addr_pins[0] == byte_pin)) {
        // fire-40-a JSON config was a hack - addr pin 0 is really pin 37
        addr_pins[0] = 37;
    }
}

EPIO_EXPORT int32_t onerom_lens_get_rom_size(void) {
    const sdrr_rom_info_t *rom = get_first_rom_info();
    if (!rom) {
        return -1; // No ROM available
    }

    assert(rom->rom_type < NUM_CHIP_TYPES);
    uint32_t size = chip_size_from_type[rom->rom_type];

    return size;
}

EPIO_EXPORT uint8_t onerom_lens_get_num_addr_bits(void) {
    int32_t rom_size = onerom_lens_get_rom_size();
    if (rom_size == -1) {
        return 0; // No ROM available
    }

    for (int ii = 0; ii < 20; ii++) {
        if (rom_size == (1 << ii)) {
            return ii;
        }
    }

    return 0; // Size not recognised
}

EPIO_EXPORT uint8_t onerom_lens_get_num_data_bits(void) {
    const sdrr_rom_info_t *rom = get_first_rom_info();
    if (!rom) {
        return 0; // No ROM available
    }

    assert(rom->rom_type < NUM_CHIP_TYPES);
    uint8_t data_bits = 8;
    if (rom->rom_type == CHIP_TYPE_27C400) {
        data_bits = 16;
    }

    return data_bits;
}

// Step the emulator forward by N cycles
EPIO_EXPORT void onerom_step(uint32_t cycles) {
    if (g_epio) {
        epio_step_cycles(g_epio, cycles);
    }
}

// Drive address and control lines
// addr: address to drive (up to 24 bits)
// num_addr_bits: number of address bits to drive (13, 14, 15, etc.)
// cs1, cs2, cs3: chip select states (0=low, 1=high, 2=not driven)
// x1, x2: additional control signals (0=low, 1=high, 2=not driven)
EPIO_EXPORT void onerom_drive_pins(
    uint32_t addr,
    uint8_t num_addr_bits,
    uint8_t cs1,
    uint8_t cs2,
    uint8_t cs3,
    uint8_t x1,
    uint8_t x2,
    uint8_t ce,
    uint8_t oe,
    uint8_t byte
) {
    if (!g_epio) return;
    
    uint64_t drive_mask = 0;
    uint64_t level_mask = 0;
    
    // Address lines
    for (int ii = 0; ii < num_addr_bits; ii++) {
        drive_mask |= (1ULL << addr_pins[ii]);
        if (addr & (1 << ii)) {
            level_mask |= (1ULL << addr_pins[ii]);
        }
    }
    
    // Control lines
    if (cs1 < 2) {
        if (cs1_pin < NUM_GPIOS) {
            drive_mask |= (1ULL << cs1_pin);
            if (cs1) level_mask |= (1ULL << cs1_pin);
        }
    }
    if (cs2 < 2) {
        if (cs2_pin < NUM_GPIOS) {
            drive_mask |= (1ULL << cs2_pin);
            if (cs2) level_mask |= (1ULL << cs2_pin);
        }
    }
    if (cs3 < 2) {
        if (cs3_pin < NUM_GPIOS) {
            drive_mask |= (1ULL << cs3_pin);
            if (cs3) level_mask |= (1ULL << cs3_pin);
        }
    }
    if (x1 < 2) {
        if (x1_pin < NUM_GPIOS) {
            drive_mask |= (1ULL << x1_pin);
            if (x1) level_mask |= (1ULL << x1_pin);
        }
    }
    if (x2 < 2) {
        if (x2_pin < NUM_GPIOS) {
            drive_mask |= (1ULL << x2_pin);
            if (x2) level_mask |= (1ULL << x2_pin);
        }
    }
    if (ce < 2) {
        if (ce_pin < NUM_GPIOS) {
            drive_mask |= (1ULL << ce_pin);
            if (ce) level_mask |= (1ULL << ce_pin);
        }
    }
    if (oe < 2) {
        if (oe_pin < NUM_GPIOS) {
            drive_mask |= (1ULL << oe_pin);
            if (oe) level_mask |= (1ULL << oe_pin);
        }
    }
    if (byte < 2) {
        if (byte_pin < NUM_GPIOS) {
            drive_mask |= (1ULL << byte_pin);
            if (byte) level_mask |= (1ULL << byte_pin);
        }
    }
    
    epio_drive_gpios_ext(g_epio, drive_mask, level_mask);
}

EPIO_EXPORT void onerom_drive_addr(
    uint32_t addr,
    uint8_t cs_active,
    uint8_t bit_mode
) {
    if (!g_epio) return;

    if ((bit_mode != 8) && (bit_mode != 16)) {
        printf("Invalid bit mode: %d\n", bit_mode);
        return; // Invalid bit mode
    }

    sdrr_rom_type_t rom_type = onerom_lens_get_rom_type();
    assert(rom_type != INVALID_CHIP_TYPE);
    assert(rom_type < NUM_CHIP_TYPES);

    if ((bit_mode == 16) && (rom_type != CHIP_TYPE_27C400)) {
        printf("16-bit mode only supported for 27C400 ROMs\n");
        return;
    }

    uint8_t cs_val = cs_active ? 0 : 1; // Active low

    uint8_t addr_bits = onerom_lens_get_num_addr_bits();
    assert(addr_bits <= 19);
    int32_t rom_size = onerom_lens_get_rom_size();
    assert(rom_size != -1);
    
    switch (rom_type) {
        case CHIP_TYPE_2316:
        case CHIP_TYPE_23128:
            onerom_drive_pins(
                addr,
                addr_bits,
                cs_val,
                cs_val,
                cs_val,
                2,
                2,
                2,
                2,
                2
            );
            break;

        case CHIP_TYPE_2332:
        case CHIP_TYPE_23256:
        case CHIP_TYPE_23512:
            onerom_drive_pins(
                addr,
                addr_bits,
                cs_val,
                cs_val,
                2,
                2,
                2,
                2,
                2,
                2
            );
            break;

        case CHIP_TYPE_2364:
        case CHIP_TYPE_231024:
            onerom_drive_pins(
                addr,
                addr_bits,
                cs_val,
                2,
                2,
                2,
                2,
                2,
                2,
                2
            );
            break;

        case CHIP_TYPE_2704:
        case CHIP_TYPE_2708:
        case CHIP_TYPE_2716:
        case CHIP_TYPE_2732:
        case CHIP_TYPE_2764:
        case CHIP_TYPE_27128:
        case CHIP_TYPE_27256:
        case CHIP_TYPE_27512:
        case CHIP_TYPE_27C010:
        case CHIP_TYPE_27C301:
        case CHIP_TYPE_27C020:
        case CHIP_TYPE_27C040:
        case CHIP_TYPE_27C080:
            onerom_drive_pins(
                addr,
                addr_bits,
                2,
                2,
                2,
                2,
                2,
                cs_val,
                cs_val,
                2
            );
            break;

        case CHIP_TYPE_27C400:
            ;
            uint32_t new_addr = bit_mode == 16 ? addr << 1 : addr;
            onerom_drive_pins(
                new_addr,
                addr_bits,
                2,
                2,
                2,
                2,
                2,
                cs_val,
                cs_val,
                bit_mode == 16 ? 1 : 0
            );
            break;

        default:
            assert(0 && "Unsupported ROM type");
            break;
    }
}

// Stop driving all GPIOs
EPIO_EXPORT void onerom_release_pins(void) {
    if (g_epio) {
        epio_drive_gpios_ext(g_epio, 0, 0);
    }
}

// Read the data pins and return as a byte
EPIO_EXPORT uint32_t onerom_read_data(uint8_t data_bits) {
    if (!g_epio) return 0;
    
    uint64_t gpio_state = epio_read_pin_states(g_epio);
    uint32_t data = 0;
    
    for (int ii = 0; ii < data_bits; ii++) {
        if (gpio_state & (1ULL << data_pins[ii])) {
            data |= (1 << ii);
        }
    }
    
    return data;
}

// Get the GPIO number for a specific address pin
EPIO_EXPORT uint8_t onerom_get_addr_pin(uint8_t bit) {
    if (bit < 32) {
        return addr_pins[bit];
    }
    return 0xFF;
}

// Get the GPIO number for a specific data pin
EPIO_EXPORT uint8_t onerom_get_data_pin(uint8_t bit) {
    if (bit < 16) {
        return data_pins[bit];
    }
    return 0xFF;
}

EPIO_EXPORT int onerom_get_pio_disassembly(
    char *buffer,
    size_t buffer_size
) {
    int wrote, total_written = 0;

    if (!g_epio) return -1;

    wrote = epio_disassemble_sm(g_epio, 0, 0, buffer, buffer_size);
    if (wrote < 0) {
        return -1;
    }
    buffer += wrote-1;
    buffer_size -= wrote-1;
    total_written += wrote-1;

    // Add 2 \ns between SMs if we have space
    if (buffer_size > 2) {
        *buffer++ = '\n';
        *buffer++ = '\n';
        buffer_size -= 2;
        total_written += 2;
    } else {
        return -1;
    }

    wrote = epio_disassemble_sm(g_epio, 0, 1, buffer, buffer_size);
    if (wrote < 0) {
        return -1;
    }
    buffer += wrote-1;
    buffer_size -= wrote-1;
    total_written += wrote-1;

    // Add 2 \ns between SMs if we have space
    if (buffer_size > 2) {
        *buffer++ = '\n';
        *buffer++ = '\n';
        buffer_size -= 2;
        total_written += 2;
    } else {
        return -1;
    }

    wrote = epio_disassemble_sm(g_epio, 0, 2, buffer, buffer_size);
    if (wrote < 0) {
        return -1;
    }
    buffer += wrote;
    buffer_size -= wrote;
    total_written += wrote;

    return total_written;
}

// Get control pin GPIO numbers
EPIO_EXPORT uint8_t onerom_get_cs1_pin(void) { return cs1_pin; }
EPIO_EXPORT uint8_t onerom_get_cs2_pin(void) { return cs2_pin; }
EPIO_EXPORT uint8_t onerom_get_cs3_pin(void) { return cs3_pin; }
EPIO_EXPORT uint8_t onerom_get_x1_pin(void) { return x1_pin; }
EPIO_EXPORT uint8_t onerom_get_x2_pin(void) { return x2_pin; }
EPIO_EXPORT uint8_t onerom_get_ce_pin(void) { return ce_pin; }
EPIO_EXPORT uint8_t onerom_get_oe_pin(void) { return oe_pin; }
EPIO_EXPORT uint8_t onerom_get_byte_pin(void) { return byte_pin; }

// Initialize the One ROM emulator
// Returns epio_t* handle on success, NULL on failure.  This handle can be used
// to directly access epio functions if needed.
EPIO_EXPORT epio_t *onerom_init(void) {
    if (g_epio) {
        return 0; // Already initialized
    }
    
    // Set up pin mappings
    setup_pin_mappings();
    
    // Run the firmware to set up the PIO programs
    firmware_main();
    
    // Check PIOs were enabled
    if (_apio_emulated_pio.pios_enabled != 1) {
        return 0;
    }
    
    // Start the PIO emulator
    g_epio = epio_from_apio();
    if (!g_epio) {
        return 0;
    }
    
    // Double check data lines are controllable as outputs by PIO block 2
    for (int ii = 0; ii < 8; ii++) {
        if (!epio_block_can_control_gpio_output(g_epio, 2, sdrr_info.pins->data[ii])) {
            printf("!!Data pin %d (GPIO %d) not controlled by PIO block 2\n", ii, sdrr_info.pins->data[ii]);
        }
    }
    for (int ii = 0; ii < 8; ii++) {
        if (sdrr_info.pins->data2[ii] < 255) {
            if (!epio_block_can_control_gpio_output(g_epio, 2, sdrr_info.pins->data2[ii])) {
                printf("!!Data pin %d (GPIO %d) not controlled by PIO block 2\n", ii+8, sdrr_info.pins->data2[ii]);
            }
        }
    }

    // Configure the DMA chain
    uint8_t bit_mode = 8;
    if (onerom_lens_get_rom_type() == CHIP_TYPE_27C400) {
        bit_mode = 16;
    }
    epio_dma_setup_read_pio_chain(
        g_epio,
        0,
        1,
        0,
        4,
        2,
        1,
        4,
        bit_mode
    );
    
    // Load ROM data into SRAM
    uint64_t *source = get_ram_rom_image_table_aligned();
    epio_sram_set(g_epio, 0x20000000, (uint8_t *)source, 512*1024);

    // Disassemble PIOs
    char buffer[4096];
    int wrote;
    wrote = epio_disassemble_sm(g_epio, 1, 0, buffer, sizeof(buffer));
    assert(wrote >= 0);
    printf("%s\n", buffer);
    wrote = epio_disassemble_sm(g_epio, 1, 1, buffer, sizeof(buffer));
    assert(wrote >= 0);
    printf("%s\n", buffer);
    wrote = epio_disassemble_sm(g_epio, 2, 0, buffer, sizeof(buffer));
    assert(wrote >= 0);
    printf("%s\n", buffer);
    wrote = epio_disassemble_sm(g_epio, 2, 1, buffer, sizeof(buffer));
    assert(wrote >= 0);
    printf("%s\n", buffer);
    wrote = epio_disassemble_sm(g_epio, 2, 2, buffer, sizeof(buffer));
    assert(wrote >= 0);
    printf("%s\n", buffer);
    
    return g_epio;
}

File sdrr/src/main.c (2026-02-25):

// One ROM Main startup code (clock and GPIO initialisation)

// Copyright (C) 2026 Piers Finlayson <piers@piers.rocks>
//
// MIT License

#include "include.h"

#if !defined(RP235X) && !defined(STM32F4)
    #error "Unsupported MCU line - please define RP235X or STM32F4"
#endif // !RP2350 && !STM32F4

const char sdrr_build_date[] = __DATE__ " " __TIME__;

#if !defined(TEST_BUILD)
#define SECTION_SDRR_RUNTIME_INFO __attribute__((section(".sdrr_runtime_info")))
#else // TEST_BUILD
#define SECTION_SDRR_RUNTIME_INFO
#endif // TEST_BUILD
sdrr_runtime_info_t sdrr_runtime_info SECTION_SDRR_RUNTIME_INFO = {
    .magic = {'s', 'd', 'r', 'r'},  // Lower case to distinguish from firmware magic
    .runtime_info_size = sizeof(sdrr_runtime_info_t),
    .image_sel = 0xFF,
    .rom_set_index = 0xFF,
    .count_rom_access = 0x00,
    .access_count = 0xFFFFFFFF,
    .rom_table = NULL,
    .rom_table_size = 0,
    .bootloader_entry = 0,
#if defined(OVERCLOCK) && (OVERCLOCK == 1)
    .overclock_enabled = 1,
#else // !OVERCLOCK
    .overclock_enabled = 0,
#endif // OVERCLOCK
    .status_led_enabled = 0,  // updated from sdrr_info in vector.c
    .swd_enabled = 0,  // updated from sdrr_info in vector.c
    .fire_vreg = FIRE_VREG_STOCK,
    .ice_freq = ICE_FREQ_NONE,
    .fire_freq = FIRE_FREQ_NONE,
    .sysclk_mhz = TARGET_FREQ_MHZ,
#if defined(RP_PIO) && (RP_PIO == 1)
    .fire_serve_mode = FIRE_SERVE_PIO,
#else // !RP_PIO
    .fire_serve_mode = FIRE_SERVE_CPU,
#endif // RP_PIO
    .bit_mode = BIT_MODE_8,
    .rom_dma_copy = 1,
    .num_data_pins = 8,
#if defined(FORCE_16_BIT) && (FORCE_16_BIT == 1)
    .force_16_bit = 1,
#else // !FORCE_16_BIT
    .force_16_bit = 0,
#endif // FORCE_16_BIT
    .reserved = 0
};

// This function checks the state of the image select pins, and returns an
// integer value, as if the sel pins control bit 0, 1, 2, 3, etc in order of
// that integer.  The first sel pin in the array is bit 0, the second bit 1, 
// etc.
uint32_t check_sel_pins(uint32_t *sel_mask) {
    uint32_t num_sel_pins, sel_value;
    uint64_t orig_sel_mask, gpio_value, sel_flip_bits;

    // Setup the pins first.  Do this first to allow any pull-ups to settle
    // before reading.
    num_sel_pins = setup_sel_pins(&orig_sel_mask, &sel_flip_bits);
    if (num_sel_pins == 0) {
        DEBUG("No image select pins");
        disable_sel_pins();
        *sel_mask = 0;
        return 0;
    }

    // Read the actual GPIO value, masked appropriately
    gpio_value = get_sel_value(orig_sel_mask, sel_flip_bits);

    // SEGGER doesn't cope well with 64-bit values, so split into two 32-bit
    // parts for logging
    DEBUG("Sel GPIO val: 0x%08lX%08lX #: %lu mask 0x%08lX%08lX", 
        (uint32_t)(gpio_value >> 32), (uint32_t)gpio_value,
        (unsigned long)num_sel_pins,
        (uint32_t)(orig_sel_mask >> 32), (uint32_t)orig_sel_mask);

    disable_sel_pins();

    // Now turn the GPIO value into a SEL value, with the bits consecutive
    // starting from bit 0, based on which pin the SEL value is.  At the same
    // time we have to update sel_mask, to match.  This gives us an integer
    // which can be used as an index into the rom set
    *sel_mask = 0;
    sel_value = 0;
    for (int ii = 0; ii < MAX_IMG_SEL_PINS; ii++) {
        uint8_t pin = sdrr_info.pins->sel[ii];
        if (pin < MAX_USED_GPIOS) {
            if (gpio_value & (1ULL << pin)) {
                sel_value |= (1 << ii);
            }
            *sel_mask |= (1ULL << ii);
        }
    }

    DEBUG("Sel value: 0x%08X mask: 0x%08X", sel_value, *sel_mask);

    // Store the value of the pins in sdrr_runtime_info
    sdrr_runtime_info.image_sel = sel_value;

    return sel_value;
}

// Check whether we shoud enter the device's bootloader and, if so, enter it.
// This is indicated via jumping SEL0, SEL1, and SEL2 - PB0-2.  These are all
// pulled up to enter the bootloader.  STM32F4 variant from rev E onwards also
// include PB7 as the most significant bit.
//
// This must be done before we set up the PLL, peripheral clocks, etc, as
// those must be disabled for the bootloader.
//
// As this checks the sel pins, cache and return the result, so we don't need
// to re-check it later.
void check_enter_bootloader(uint32_t sel_pins, uint32_t sel_mask) {
    LOG("Checking whether to enter bootloader");

    if ((sel_mask) && ((sel_pins & sel_mask) == sel_mask)) {
        // SEL pins are all high - enter the bootloader
        LOG("Entering bootloader");

        // Pause to allow the log to be received
        for (volatile int ii = 0; ii < 1000000; ii++);

        enter_bootloader();
    }

    return;
}

// Check the metadata is present
uint8_t metadata_present(const sdrr_info_t *info) {
    onerom_metadata_header_t *metadata = (onerom_metadata_header_t *)info->metadata_header;
    uint8_t present = 1;

    // Check for magic in metadata
    for (int ii = 0; ii < 16; ii++) {
        if (metadata->magic[ii] != "ONEROM_METADATA"[ii]) {
            present = 0;
            break;
        }
    }

    if (present) {
        if (metadata->version == 1) {
            LOG("Metadata v%d", metadata->version);
        } else {
            ERR("Unsupported metadata version: %d", metadata->version);
            present = 0;
        }
    } else {
        LOG("Valid metadata header not found");
    }

    return present;
}

#if !defined(TEST_BUILD)
void limp_mode(limp_mode_pattern_t pattern) {
    LOG("Limp mode %d", pattern);

    uint32_t on_time, off_time;

    if (!sdrr_runtime_info.status_led_enabled && sdrr_info.status_led_enabled) {
        DEBUG("Enabled status LED");
        setup_status_led();
    }

    if (pattern >= NUM_LIMP_MODE_PATTERNS) {
        DEBUG("!!! Invalid limp mode pattern");
        pattern = LIMP_MODE_NONE;
    }

    on_time = limp_mode_patterns[pattern].on_time;
    off_time = limp_mode_patterns[pattern].off_time;

    while (1) {
        blink_pattern(on_time, off_time, 1);
    }
}
#endif // !TEST_BUILD

// Read in firmware overrides from the selected ROM set, if present (0.6.0+)
// and modify sdrr_runtime_info accordingly.
void process_firmware_overrides(
    sdrr_runtime_info_t *runtime_info,
    const sdrr_rom_set_t *set
) {
    if (set->extra_info == 1) {
        const onerom_firmware_overrides_t *overrides = set->firmware_overrides;
        if ((overrides != NULL) && (overrides != (void*)0xFFFFFFFF)) {
#if defined(STM32F4)
            if (overrides->override_present[0] & (1 << 0)) {
                runtime_info->ice_freq = overrides->ice_freq;
                LOG("ICE freq override: %d", runtime_info->ice_freq);
            }
            if (overrides->override_present[0] & (1 << 1)) {
                runtime_info->overclock_enabled = overrides->override_value[0] & (1 << 0) ? 1 : 0;
                LOG("ICE overclock override: %d", runtime_info->overclock_enabled);
            }
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

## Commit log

2026-01-29 add Fie 28 A3 RP2354 variant
    [fire-28-a3-bom-rp2354.csv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]
2026-02-14 Add PIO emulator support via epio, and One ROM Lens (#143)
    PIO emulation allows the One ROM firmware PIO algorithm to be tested in a hosted environment.
    One ROM Lens tests the firmware within a browser and provides a logic analyzer style UI.
    Testing via PIO emulation, and One ROM Lens, are not currently built or tested via CI. That will come later.
2026-02-17 Add One ROM 40 16-bit support for 27C400 (Amiga Kickstart ROM, etc) (#147)
    [fire-40-a-bom-rp2354-and-flash.csv, fire-40-a.kicad_pcb, fire-40-a.kicad_sch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]
2026-02-20 new firmware designs
    [fire-24-e-bom-alt-ap2112k.csv, fire-28-a3-bom-rp2354.csv, fire-28-a3-bom.csv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]
2026-02-22 Release v0.6.5 - One ROM 40 and One ROM Lens support (#150)
    Also introduces extensive regression testing for PIO serving.
2026-02-25 Release v0.6.6 - bug fixes, 2704/2708 support and prototype 32 pin support (#157)
    Implements/fixes:
    #153
    #94
    #149
    #110
    #154
    #156
    #131

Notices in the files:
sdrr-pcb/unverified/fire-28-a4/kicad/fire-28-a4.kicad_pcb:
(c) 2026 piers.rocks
